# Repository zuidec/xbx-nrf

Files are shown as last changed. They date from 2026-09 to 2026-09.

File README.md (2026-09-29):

# xbx-nrf

A replacement bottom board for the **Xbox Series X|S controller (model 1914)**
built on a Nordic **nRF52840**, with a **2.4 GHz USB dongle** instead of Xbox
Wireless / Bluetooth: a low-latency proprietary link, like 8BitDo or Logitech
Lightspeed. The stock top board and shell stay.

> **Status:** early design and prototyping. Open tasks: [todo.md](todo.md).

## Architecture

```
┌─────────── Controller ───────────┐          ┌──── Dongle ────┐
│ Stock top board ─J3─ new board   │ 2.4 GHz  │ nRF52840 + USB │
│ buttons (PCAL6416)  nRF52840     │◀────────▶│ XInput / HID   │──▶ PC
│ power latch, boost  radio,       │ESB/Gazell│ gamepad        │
│ USB-C, 2×AA input   sticks,      │          │                │
│                     triggers,    │          │                │
│                     rumble       │          │                │
└──────────────────────────────────┘          └────────────────┘
```

## Design decisions (locked)

| Area | Decision |
|---|---|
| Target | Xbox Series X\|S (1914); Elite Series 2 (1797) maybe later |
| Scope | New **bottom board only**; stock top board, shell, triggers, motors reused |
| MCU | **nRF52840**: certified module (controller), Nordic PCA10059 (dongle) |
| Audio | **None in v1** |
| Wireless | **ESB/Gazell** 2.4 GHz; rumble/LED in ACK payloads |
| Multiplayer | One dongle: up to **7 paired**, **4 connected**; 1 kHz with 1–2, 500 Hz with 3–4 (time slots) |
| Dongle USB | **HID gamepad** (first) and **XInput** (`045E:028E`), switchable. No Xbox console support |
| Battery | **Rechargeable AAs only** (NiMH or regulated 1.5 V Li-ion AAs) |
| Power | Stock top board latch and boost converters, via J3 |
| Rumble | 2× **Allegro A3910**, stock wiring, 8 GPIOs |
| Buttons | Mostly via the top board's **PCAL6416** I2C expander |

> [!WARNING]
> **Never put a bare Li-ion cell on the AA contacts**: the stock boost
> converters pass it straight to the 3.3 V rail
> ([docs/hardware.md](docs/hardware.md)).

## Hardware

Our board plugs into the stock top board's 14-pin **J3**: power rails, USB, I2C
to the button expander, and Guide / Pair / power-hold signals.

| Doc | Covers |
|---|---|
| [docs/hardware.md](docs/hardware.md) | Top board power, J3 pinout, antennas |
| [docs/pcal6416.md](docs/pcal6416.md) | Button expander: button map, registers |
| [docs/a3910.md](docs/a3910.md) | Rumble drivers: wiring, logic table |

## Firmware

Two Zephyr apps, `firmware/xbx-nrf` (controller) and `firmware/dongle`, on the
**nRF Connect SDK v3.4.1** (pinned). Prototyped on Pro Micro nRF52840 boards;
the 1 kHz radio link works.

```sh
ncs-shell                                  # SDK toolchain environment
firmware/build-unsigned.sh xbx-nrf         # development build
firmware/build-signed.sh dongle <board>    # signed release build
```

| Doc | Covers |
|---|---|
| [docs/building.md](docs/building.md) | SDK setup, versions, build scripts |
| [docs/flashing.md](docs/flashing.md) | Flashing and debugging |
| [docs/protocol.md](docs/protocol.md) | Radio and USB HID protocols |
| [docs/gip.md](docs/gip.md) | Xbox GIP protocol notes (optional mode) |
| [docs/signing.md](docs/signing.md) | Firmware signing (MCUboot, keys) |

## Repository layout

```
docs/                project notes (Obsidian)
firmware/
  common/            shared code (include/protocol.h)
  xbx-nrf/           controller app
  dongle/            dongle app
  ncs-version        pinned SDK + toolchain
  check-sdk.sh       version check for the build scripts
  build-unsigned.sh  development build
  build-signed.sh    signed release build
pcb/xbx-nrf/         KiCad project (lib/: symbols, footprints, 3D)
references/          schematics, scans, datasheets, pinouts, CAD outline
todo.md              task list (Obsidian)
```

## References

- [Top board schematic](references/XB1%201914%20TOP%20BOARD.pdf)
- [Bottom board schematic](references/XB1_1914_BOTTOM_BOARD_SOME_VALUES.pdf)
- [SoC module schematic](references/XB1_1914_SOC_SOME_VALUES.pdf)
- [Connector pinouts and test points](references/controller-pinouts.txt)
- [SoC pinout](references/soc-pinout.txt)
- Datasheets: 
  [A1304](references/A1304-Datasheet.pdf),
  [A3910](references/A3910-datasheet.pdf),
  [PCAL6416A](references/PCAL6416A-datasheet.pdf)
- [AcidMods — XB1 controller PCB scans](https://acidmods.com/forum/index.php?topic=44547.120)
- [GP2040-CE](https://github.com/OpenStickCommunity/GP2040-CE)(XInput reference)

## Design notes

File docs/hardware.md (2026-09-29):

---
title: Hardware (stock top board & J3)
created: 2026-09-29
updated: 2026-09-29
tags:
  - xbx-nrf
  - reference
  - hardware
aliases:
  - hardware
  - J3
  - top board
---

# Hardware: stock top board & J3

The stock **top board** and the **J3** connector our bottom board plugs into.
Related: [[docs/pcal6416|PCAL6416 (buttons)]], [[docs/a3910|A3910 (rumble)]],
[[todo#1. Verify / reverse-engineer (stock hardware)]].

Sources: [[references/XB1 1914 TOP BOARD.pdf]],
[[references/controller-pinouts.txt]], [[references/soc-pinout.txt]].

> [!warning] No bare Li-ion cells
> U5/U6 are boost-only: a 4.2 V cell on the AA contacts passes through to the
> 3.3 V rail, above the nRF52840's 3.6 V max. Use rechargeable AAs (NiMH, or
> regulated 1.5 V Li-ion AAs).

## Top board power (stock, reused)

| Part | Function |
|---|---|
| Q6/Q7 | Battery → `3v/B+` switch; disconnects the AAs when USB is present |
| U5 TPS613221 | `3v/B+` → **3.3 V** (logic) |
| U6 TPS613226 | `3v/B+` → **3.6 V** (rumble) |
| U1 MP1476L | USB 5 V → `3v/B+`; powered on whenever USB is plugged in |
| SW13 + Q8 / SW2 + Q14 → Q9 | Guide or Pair powers on; J3 pin 9 holds it |

The latch is probably **not self-holding**: firmware must raise J3 pin 9 before
the button is released ([[todo#Power latch (top board)]]).

## J3: top ↔ bottom board connector

| Pin | Signal | Direction (bottom board) | Notes |
|---|---|---|---|
| 1 | 3.6 V | Power in | Rumble supply |
| 2 | GU (Guide) via D27 | Input | Active-low; pull-up on our board |
| 3 | 3v/B+ | Power in | Switched battery rail; battery sense |
| 4 | 3.3 V | Power in | nRF supply |
| 5 | SCL | Output | I2C to the PCAL6416 |
| 6 | LED control | Output | Guide LED (Q3) |
| 7 | SDA | Bidirectional | I2C to the PCAL6416 |
| 8 | USB D+ | Bidirectional | From the USB-C port |
| 9 | ~RESET / power hold | Output | High = power held + expander out of reset. *Verify* |
| 10 | USB D− | Bidirectional | |
| 11 | ? | — | Also J7 pin 1 (Play & Charge?). *Unknown* |
| 12 | VBUS | Input | USB detection |
| 13 | Pair sense via D30 | Input | Suspected; active-low. *Verify* |
| 14 | GND | — | |

*Verify* / *Unknown*: [[todo#J3/J5 connector (top ↔ bottom)]].

## Antennas (plan: reuse the stock ones)

Two feeds on the top board (`ANT` via J5/J6, `ANT1` via J8), each with a
matching network; the stock SoC board reaches them through coax connectors J1,
J2. We'll reuse the 2.4 GHz one, after verification (required before ordering
the PCB; [[todo#MCU / radio]]).

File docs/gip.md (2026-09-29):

---
title: GIP (Xbox One/Series USB protocol) notes
created: 2026-09-29
tags:
  - xbx-nrf
  - reference
  - usb
aliases:
  - GIP
  - MS-GIPUSB
---

# GIP: Gaming Input Protocol over USB

Microsoft's protocol for Xbox One/Series controllers. Only needed for an
optional future **GIP dongle mode** (impulse triggers on Windows; see
[[todo#Future / v2]]). Our own protocols: [[docs/protocol]].

Source: [[references/windows_protocols-ms-gipusb.pdf]] (MS-GIPUSB, 2024; §
numbers below). Reference implementation: GP2040-CE's Xbox One mode (MIT).

## Feasibility summary

- **Impulse triggers:** one simple message (`0x09`, below).
- **No authentication needed on PC:** list the opt-out interface GUID
  `7a34ce77-7de2-45c6-8ca4-0042c08bd94a` in the metadata; "the host succeeds
  the security exchange by default" (§5.1). Xbox consoles still require it.
- **Metadata** is the hard part: written as JSON, compiled to a binary blob with
  Microsoft's metadata compiler (in the "gipdocs" download, not in this spec).
  Windows requests it; Linux `xpad` doesn't.
- **Linux:** `xpad` supports GIP but sends trigger motor levels as 0, and Linux
  force feedback has only 2 rumble values. Trigger rumble would need SDL/Steam
  talking to the device directly. **Test with a genuine controller first**
  ([[todo#GIP dongle mode]]).
- **IDs:** the spec requires the maker's own VID; `xpad` only auto-binds known
  vendors (Microsoft's VID for a personal build, or bind manually).

## USB (§2.2.3–2.2.9)

| Item | Value |
|---|---|
| Device / interface class | `FF` / subclass `47` / protocol `D0` |
| Endpoints | Interface 0: 64-byte interrupt IN + OUT |
| Polling | "up to 4 ms / 250 Hz" (1 ms presumably allowed; verify) |
| Config attributes | `0xA0` (bus powered, remote wakeup) |
| Serial string | 32 hex digits = 64-bit Device ID |
| MS OS descriptor | String `MSFT100`, vendor code `0x90`; compatible ID `XGIP10` |

## Message header (§2.2.10)

| Byte | Field | Notes |
|---|---|---|
| 0 | Type | Bits 7:5 data class (000 command, 001 low latency, 011 audio), 4:0 message number |
| 1 | Flags | 7 fragment, 6 first fragment, 5 **system**, 4 **ACK requested**, 2:0 expansion index |
| 2 | Sequence | Wrapping, `0x00` reserved; global pool, except security / extended / audio / vendor messages (own pools) |
| 3 | Length | Payload bytes; bit 7 = length continues in the next byte |

MTU 64 bytes (commands, input). Larger messages (metadata) are fragmented with
ACKs (`0x01`) at least every 100 ms (§3.1.5.1–3.1.5.2).

## Startup (§1.3.1, §2.2.1–2.2.2)

1. Device sends **Hello** (`0x02`) every 500 ms until the host answers.
2. Host requests **metadata** (`0x04`, up to 4× at 500 ms; reply < 500 ms) or
   sends **Set Device State: Start** directly (metadata is cached by VID/PID
   + firmware major/minor).
3. **Start** → device sends **Status** (`0x03`) and a first **input report**
   reflecting the current state.
4. Host sends **Guide LED** (`0x0A`) and **motor** (`0x09`) commands.

## Messages we'd need

| Type | Dir | Message | Notes |
|---|---|---|---|
| `0x01` | ↕ | Protocol control (ACK) | Reliable / fragmented transfers |
| `0x02` | ↑ | Hello | 28 bytes: Device ID, VID, PID, FW major/minor/build/rev, HW version, RF/security/GIP versions (all `1.0`) |
| `0x03` | ↑ | Status | Extended format (4 bytes): on start, power off, charge/battery changes, every 1 s for 10 s then every 20 s |
| `0x04` | ↕ | Metadata request / response | Response fragmented, ends with Metadata Complete (flags `0xA0`) |
| `0x05` | ↓ | Set device state | `00` Start, `01` Stop, `04` Off, `05` Quiesce (clear motors), `07` Reset |
| `0x06` | ↕ | Security | Skipped via the opt-out GUID |
| `0x07` | ↑ | Guide button | 2-byte payload; after power-on, don't report the press until its first release |
| `0x09` | ↓ | **Direct motor** | Below |
| `0x0A` | ↓ | Guide LED | Pattern (`01` on, …) + intensity 0–47 % |
| `0x20` | ↑ | **Gamepad input** | Below; send only when something changed |

### Direct motor command (`0x09`, §3.1.5.6.1)

Header `09 00 <seq> 09`, then:

| Byte | Field | Notes |
|---|---|---|
| 4 | Command | `0x00` |
| 5 | Motor mask | bit 3 left impulse, 2 right impulse, 1 left grip, 0 right grip |
| 6 | Left impulse | 0–100 % |
| 7 | Right impulse | 0–100 % |
| 8 | Left grip (heavy) | 0–100 % |
| 9 | Right grip (light) | 0–100 % |
| 10 | Duration | ×10 ms; `0` = stop all |
| 11 | Delay | ×10 ms |
| 12 | Repeat | Count; `0` = play once |

Maps onto our `rumble[4]` (scale 0–100 → 0–255). Duration/delay/repeat could
be forwarded so the controller plays patterns itself.

### Gamepad input report (`0x20`, §3.1.5.6.1.1)

Header `20 00 <seq> 0E` (14-byte payload; `20` = 32 bytes with Share):

| Byte | Field |
|---|---|
| 4 | `0x04` Menu, `0x08` View, `0x10` A, `0x20` B, `0x40` X, `0x80` Y |
| 5 | `0x01` Up, `0x02` Down, `0x04` Left, `0x08` Right, `0x10` LB, `0x20` RB, `0x40` LS, `0x80` RS |
| 6–7 | Left trigger 0–1023 |
| 8–9 | Right trigger 0–1023 |
| 10–17 | LX, LY, RX, RY: −32768…32767 |
| 18 | *(Share variant)* Console Function Map: `0x01` while Share is held, else `0x00`; rest zero |

Guide isn't in this report (it's `0x07`). Bit order differs from our radio
`buttons` (XInput layout), so the dongle remaps.

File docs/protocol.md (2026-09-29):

---
title: xbx-nrf protocols (radio + USB HID)
created: 2026-09-29
tags:
  - xbx-nrf
  - firmware
  - reference
aliases:
  - protocol
  - radio protocol
  - HID report
---

# xbx-nrf protocols

Two links: **radio** (controller ↔ dongle, implemented) and **USB HID** (dongle
↔ PC, planned). XInput and GIP modes reuse the radio data; see [[docs/gip]] for
GIP. Tasks: [[todo#Link]], [[todo#Dongle]].

## Radio (controller ↔ dongle)

Source of truth: `firmware/common/include/protocol.h`. **Version 1**
(`XBX_PROTOCOL_VERSION`); both boards must run the same version.

### Link

| Setting | Value |
|---|---|
| Protocol | Nordic ESB, dynamic payload length, selective auto-ACK |
| Bit rate | 2 Mbps, fast ramp-up |
| Channel | 76 (2476 MHz), fixed for now (`XBX_RF_CHANNEL`) |
| Address | base 0 `58 42 58 31` ("XBX1"), prefix `E7`, pipe 0 (fixed until pairing) |
| TX power | +8 dBm, both ends (`XBX_TX_POWER_DBM`) |
| Roles | Controller = PTX, dongle = PRX |
| Report rate | 1000 Hz from hardware TIMER3 (`XBX_REPORT_PERIOD_US`) |
| Retries | 1, 450 µs apart (ESB minimum 435 µs); stale reports are flushed, never resent late |
| Max payload | 32 bytes (`CONFIG_ESB_MAX_PAYLOAD_LENGTH`) |

Every 1 ms the controller sends an **input report**. The dongle's ESB ACK
carries the **output report** queued for it (one is always kept queued), so
rumble/LED data costs no extra transmissions. All fields are little-endian.

### Input report (controller → dongle), 23 bytes

| Offset | Size | Field | Notes |
|---|---|---|---|
| 0 | 1 | `type` | `0x01` (`XBX_MSG_INPUT`) |
| 1 | 2 | `seq` | +1 per report actually sent; gaps = lost over the air. Gap ≥ 0x8000 = controller restart |
| 3 | 2 | `buttons` | Bitmap below, 1 = pressed |
| 5 | 2 | `lx` | Left stick X, −32768…32767 |
| 7 | 2 | `ly` | Left stick Y |
| 9 | 2 | `rx` | Right stick X |
| 11 | 2 | `ry` | Right stick Y |
| 13 | 2 | `lt` | Left trigger, 0…1023 |
| 15 | 2 | `rt` | Right trigger, 0…1023 |
| 17 | 1 | `buttons_ext` | bit 0 Share, bit 1 Pair |
| 18 | 1 | `battery` | 0…100 %, `0xFF` = unknown |
| 19 | 4 | `timestamp_us` | Controller uptime at send (latency tests) |

`buttons` uses the **XInput `wButtons` layout**, so XInput mode passes it
through:

| Bit | Button | Bit | Button |
|---|---|---|---|
| 0 | D-pad up | 8 | LB |
| 1 | D-pad down | 9 | RB |
| 2 | D-pad left | 10 | Guide |
| 3 | D-pad right | 11 | *(unused)* |
| 4 | Menu (XInput START) | 12 | A |
| 5 | View (XInput BACK) | 13 | B |
| 6 | LS (stick click) | 14 | X |
| 7 | RS | 15 | Y |

### Output report (dongle → controller, ACK payload), 8 bytes

| Offset | Size | Field | Notes |
|---|---|---|---|
| 0 | 1 | `type` | `0x02` (`XBX_MSG_OUTPUT`) |
| 1 | 1 | `seq` | +1 per report queued |
| 2 | 4 | `rumble[4]` | Heavy, light, LT, RT; 0…255 |
| 6 | 1 | `led` | Guide LED brightness, 0…255 |
| 7 | 1 | `flags` | Reserved, 0 |

### Changing the protocol
- Bump `XBX_PROTOCOL_VERSION` and the `_Static_assert` sizes; update this page.
- Mismatched versions show up as `bad` packets on the dongle (length/type
  check).
- Planned for v2: pairing, multiple controllers, time slots
  ([[#Pairing & multiple controllers (planned, protocol v2)]]).

| Version | Change |
|---|---|
| 0 | Initial: 22-byte input report, 8-bit `seq` |
| 1 | 16-bit `seq` (23-byte input report) |

## Pairing & multiple controllers (planned, protocol v2)

> [!warning] Draft
> Design agreed 2026-09-29, not implemented. Numbers marked *(tune)* are
> starting values to adjust on hardware.

### Requirements
- A controller only ever talks to the dongle it's paired with.
- Several dongle/controller sets work side by side.
- One dongle: **up to 7 paired** controllers, **up to 4 connected**.
- Report rate: **1 kHz** with 1–2 connected, **500 Hz** with 3–4.
- Pairing needs a deliberate action on **both** sides, and doesn't interrupt
  controllers already playing on that dongle.

### Addresses and channels
- ESB gives a receiver 8 **pipes**: pipe 0 on base address 0, pipes 1–7 on base
  address 1, each pipe with its own 1-byte prefix.

| Pipe | Address | Use |
|---|---|---|
| 0 | Fixed **pairing address** `"XBXP"` + prefix `E7`, same on every dongle | Pairing only; enabled only while the dongle is in pairing mode |
| 1–7 | Dongle's **random base address 1** + 7 distinct random prefixes | One per paired controller |

- The radio drops packets for addresses it isn't listening on (plus CRC), so a
  controller can't reach another dongle, and nobody reaches the pairing pipe
  unless that dongle is in pairing mode.
- Random addresses are chosen once, at first use; patterns resembling the
  preamble (mostly `0x55`/`0xAA`) are rejected.
- **Channel:** each dongle picks the quietest channel (RSSI sampling) from a
  fixed **candidate list**, at first use: **24, 49, 74, 76, 78** *(tune)*,
  i.e. 2424–2478 MHz in the gaps between Wi-Fi channels 1/6/11, clear of BLE
  advertising. Channel hopping later follows a per-dongle sequence.
- **IDs:** each nRF52840's factory-unique 64-bit `DEVICEID` (FICR).

### ESB constraint: answers take two transmissions
The receiver ACKs ~150 µs after a packet arrives, before firmware has read it,
so an ACK can only carry what was queued **before** the packet came in. Every
request is therefore repeated: the first copy gets a plain ACK ("heard you"),
the dongle then queues its answer, and a later copy gets the answer in its ACK.
The controller simply repeats each message every ~2 ms until the answer
arrives.

### Pairing mode
| Side | Enter | While active | Timeout |
|---|---|---|---|
| Dongle | Press its button; automatic at plug-in if never paired | Enables pipe 0 on its own channel; time slots keep running; LED fast blink | 30 s *(tune)* |
| Controller | Hold **Pair** ~3 s, or power on with Pair held | Drops its current link, scans; Guide LED fast blink | 30 s *(tune)* |

Both windows just need to overlap; press order doesn't matter.

### Exchange

```
controller                                   dongle (own channel)
  scan candidate channels:
  PAIR_REQ on pipe 0 (pairing address)  ─▶   (pipe 0 open only in pairing mode)
      no ACK → next channel (~0.6 ms each)
      ACK    → stay, repeat every ~2 ms
                                              check RSSI, version, ambiguity;
                                              pick pipe; queue PAIR_OFFER
  PAIR_REQ (repeat)                     ─▶
                                        ◀─   ACK: PAIR_OFFER
  check nonce; switch to assigned pipe
  PAIR_CONFIRM on its pipe (repeat)     ─▶
                                              save entry to flash;
                                              queue PAIR_DONE on that pipe
  PAIR_CONFIRM (repeat)                 ─▶
                                        ◀─   ACK: PAIR_DONE
  save to flash; both leave pairing mode (LEDs solid), dongle closes pipe 0
  controller joins normally (below)
```

Once both sides are in pairing mode, this takes well under a second.

**Dongle checks on `PAIR_REQ`** (step "check" above):
- **Proximity:** RSSI ≥ **−50 dBm** *(tune)*, i.e. held close; otherwise
  ignored.
- **Version:** `proto_ver` must match; otherwise `PAIR_OFFER` with status
  "version mismatch" and both show the error blink.
- **Ambiguity:** a second, different `ctrl_id` in the same window → abort, error
  blink.
- **Pipe:** known `ctrl_id` → same pipe; else a free pipe; else the **least
  recently connected** entry's pipe.

**Controller checks on `PAIR_OFFER`:**
- `nonce` must echo its own (not someone else's offer).
- Offers from two different `dongle_id`s in one window (two dongles pairing
  nearby) → abort, error blink.

**Commit order:** the dongle saves when it receives `PAIR_CONFIRM` on the new
pipe (proof the controller has the offer and switched); the controller saves
when it receives `PAIR_DONE`. Flash writes run from a work queue, never in the
radio interrupt.

### Pairing messages
Payloads (little-endian, sizes to finalize):

| Type | Message | Pipe | Fields | Size |
|---|---|---|---|---|
| `0x10` | PAIR_REQ | 0 | `ctrl_id`[8], `proto_ver`, `nonce`[4] | 14 |
| `0x11` | PAIR_OFFER | 0 (ACK) | `status`, `dongle_id`[8], `nonce`[4], `base_addr1`[4], `prefix`, `pipe` (1–7), `channel` | 21 |
| `0x12` | PAIR_CONFIRM | assigned | `ctrl_id`[8], `dongle_id`[8] | 17 |
| `0x13` | PAIR_DONE | assigned (ACK) | `status` | 2 |

Byte 0 of each payload is the type. `status`: `0` ok, `1` version mismatch, `2`
aborted (ambiguity).

### Failure handling
| Situation | Result |
|---|---|
| Only one side in pairing mode | Controller keeps scanning; both time out; nothing changes |
| Controller too far away | Ignored; timeout |
| Two controllers at one dongle | Dongle aborts, error blink |
| Two dongles pairing nearby | Controller aborts, error blink |
| Version mismatch | Error blink on both |
| `PAIR_DONE` lost | Controller repeats `PAIR_CONFIRM`; dongle re-sends `PAIR_DONE` |
| Controller never gets `PAIR_DONE` | Controller saves nothing; the dongle's entry is reused on re-pair or replaced later |
| Re-pairing a known controller | Same pipe, entry updated |

### Stored data (Zephyr settings, flash)
- **Dongle:** `base_addr1`, 7 prefixes, channel; 7 entries of `ctrl_id`, pipe,
  last-connected counter.
- **Controller:** `dongle_id`, `base_addr1`, prefix, pipe, channel.
- Factory reset: e.g. Pair + View held at power-on *(tune)*; the dongle's
  button held ~10 s *(tune)*.

### Time slots (TDMA)
One radio can't receive two controllers at once, so the dongle runs a
repeating **frame** and gives each connected controller its own **slot**:

| Connected | Frame | Slots | Rate per controller |
|---|---|---|---|
| 1–2 | 1 ms | 2 × 500 µs | 1000 Hz |
| 3–4 | 2 ms | 4 × 500 µs | 500 Hz |

- A transaction (report + ACK) takes ~200–300 µs, so 500 µs slots leave margin.
- **Sync:** each ACK carries a timing correction (report arrival vs. slot
  start, measured by the dongle). The controller trims its TIMER3 period.
  Crystal drift is ~20 ns/ms, so per-frame correction is plenty.
- **No retries** within a frame: a lost report is replaced by the next one.
- **Frame changes** (2nd → 3rd controller and back): the dongle announces the
  new frame length and each slot in ACK payloads, effective from a given frame
  number, so all controllers switch together.
- Pairing traffic on pipe 0 is rare and short; it may cost an occasional report
  in an active slot.

### Connecting and disconnecting
- **Join:** a paired, unsynced controller sends reports on its pipe every
  ~10 ms with random jitter until an ACK assigns it a slot. Rare collisions with
  active slots cost at most one report.
- **Full (4 connected):** the dongle answers with a "full" status; the
  controller shows it and retries slowly, then powers off after a timeout.
- **Drop:** no report from a slot for ~100 ms *(tune)* → slot freed, USB reports
  a disconnect.
- **Player number** = slot (USB interface order; optionally shown on the Guide
  LED).

### Message changes (v2)
| Type | Message | Direction |
|---|---|---|
| `0x01` | Input report (unchanged) | controller → dongle |
| `0x02` | Output report + sync fields (below) | dongle → controller |
| `0x10`–`0x13` | Pairing ([[#Pairing messages]]) | both |

Output report additions (sizes to finalize): slot index, frame length, timing
correction (signed µs), status (`ok` / `full` / `frame change at N`), and link
quality (RSSI, for [[todo#Dynamic TX power]]).

### Later
- **Encryption / authentication:** ESB has none; a key from pairing (ECDH) +
  AES-CCM per packet would stop spoofed input. The nRF52840 has hardware for
  both. Not planned for v1.

## USB HID mode (dongle ↔ PC), planned

> [!warning] Draft
> Not implemented yet (M2). The layout below is the starting proposal; finalize
> it with the report descriptor and update this page.

- Standard HID gamepad (Generic Desktop / Game Pad), Zephyr USB HID class.
- Our own VID/PID (not Microsoft's); 1 ms interrupt IN endpoint.
- **One HID interface per player slot (4)**, so the OS sees 4 gamepads. XInput
  mode likewise emulates the **Xbox 360 Wireless Receiver** (4 interfaces with
  connect/disconnect; supported by `xpad`, Steam, Windows).
- Carries the full radio data: 16-bit sticks, 10-bit triggers, every button
  including Share.

### Input report (dongle → PC), proposal

| Offset | Size | Field | HID usage |
|---|---|---|---|
| 0 | 1 | Report ID `0x01` | |
| 1 | 2 | Buttons 1–16 | Button page, same bit order as radio `buttons` |
| 3 | 1 | Buttons 17–18 (Share, Pair) + 6 bits padding | Button page |
| 4 | 2 | Left stick X | Generic Desktop X, −32768…32767 |
| 6 | 2 | Left stick Y | Y |
| 8 | 2 | Right stick X | Rx |
| 10 | 2 | Right stick Y | Ry |
| 12 | 2 | Left trigger | Z, 0…1023 |
| 14 | 2 | Right trigger | Rz, 0…1023 |

### Output report (PC → dongle), proposal

| Offset | Size | Field | HID usage |
|---|---|---|---|
| 0 | 1 | Report ID `0x02` | |
| 1 | 4 | Rumble heavy, light, LT, RT (0…255) | Vendor page `0xFF00` |
| 5 | 1 | Guide LED (0…255) | Vendor page `0xFF00` |

Maps 1:1 onto the radio output report. Games won't use it (no standard HID
rumble); it's for our own tools and possibly Steam later.

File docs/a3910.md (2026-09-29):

---
title: A3910 rumble motor driver (U4/U5, bottom board)
created: 2026-09-28
updated: 2026-09-29
tags:
  - xbx-nrf
  - reference
  - ic
aliases:
  - A3910
  - rumble driver
---

# A3910 — rumble motor drivers (U4, U5 on the bottom board)

Allegro dual half-bridge driver. The stock bottom board uses two, one
half-bridge per rumble motor. **Our board copies this: 2× A3910, 8 GPIOs.**
Tasks: [[todo#Rumble]].

> [!note] Designator clash
> Bottom board **U4/U5 = A3910**; top board **U4 =
> [[docs/pcal6416|PCAL6416]]**.

Sources: [[references/XB1_1914_BOTTOM_BOARD_SOME_VALUES.pdf]],
[[references/A3910-datasheet.pdf]] (Rev. 3), [[references/soc-pinout.txt]].

## Key specs

| Parameter | Value |
|---|---|
| Supply (VBB) | 2.5–5.5 V; **3.6 V** here (J3 pin 1) |
| Output current | 500 mA max per output |
| R<sub>DS(on)</sub> at 3 V, 400 mA | high side 1.1 Ω typ / 1.4 max, low side 0.5 / 0.65 Ω |
| Supply current | 0.3 mA typ (50 kHz PWM); **< 1 µA sleep** |
| Logic thresholds | V<sub>IL</sub> ≤ 0.5 V, **V<sub>IH</sub> ≥ VBB/2 = 1.8 V**: 3.3 V GPIOs are fine |
| Input pull-downs | 100 kΩ; 33 µA per input held high |
| Logic input abs. max | −0.3 to 6 V |
| Protection | Crossover protection; thermal shutdown 165 °C |
| Thermal resistance | 49 °C/W (4-layer), 92 °C/W (2-layer) |
| Package | 2 × 2 mm DFN-8 + exposed pad, 0.5 mm pitch |
| Part | **A3910EEETR-T** (LCSC C150818) |

## Pinout

| Pin | Name | Function |
|---|---|---|
| 1 | HIN1 | High-side input, bridge 1 |
| 2 | LIN1 | Low-side input, bridge 1 |
| 3 | LIN2 | Low-side input, bridge 2 |
| 4 | HIN2 | High-side input, bridge 2 |
| 5 | OUT2 | Output 2 |
| 6 | GND | Ground |
| 7 | VBB | Supply |
| 8 | OUT1 | Output 1 |
| 9 (EP) | PAD | → GND (thermal) |

## Logic table

Motors connect **between OUTx and GND**.

| HINx | LINx | OUTx | Motor |
|---|---|---|---|
| 0 | 0 | Hi-Z | **Coast**; sleep if all four inputs < 100 mV |
| 1 | 0 | High | **Drive** |
| 0 | 1 | Low | **Brake** |
| 1 | 1 | Hi-Z | Coast (crossover protection) |

## Stock wiring (bottom board)

| Driver | Output | Motor | Output TP | Input TPs | Clamp diode |
|---|---|---|---|---|---|
| U4 | OUT1 (8) | **LT** impulse trigger | TP27 | TP104–TP107 | CR3 |
| U4 | OUT2 (5) | **Heavy** (left grip) | TP28 | ↑ | CR1 |
| U5 | OUT1 (8) | **RT** impulse trigger | TP29 | TP108–TP111 | CR4 |
| U5 | OUT2 (5) | **Light** (right grip) | TP30 | ↑ | CR2 |

- Motor pads: SQ1/2 (LT), SQ3/4 (Heavy), SQ5/6 (RT), SQ7/8 (Light); second
  terminal to GND.
- CR1–CR4: clamp diodes output → GND. C5/C6/C15/C16 across the motors: not
  fitted. VBB decoupling values: not recorded.
- SoC pins (from `soc-pinout.txt`): U4 pins 1–4 → 49, 50, 48, 47; U5 pins 1–4 →
  59, 61, 18, 62. TP → pin mapping unconfirmed.

## Our design

8 GPIOs (HIN + LIN per motor): every motor can drive, brake and coast.

> [!tip] Freeing pins later
> Tie **LIN to GND on Heavy and Light** (−2 GPIOs). They then only drive and
> coast, which is fine for grip motors; LT/RT keep fast braking.

### Schematic checklist
- [ ] 2× A3910EEETR-T, VBB from J3 pin 1, exposed pad to GND.
- [ ] VBB decoupling per driver, ≥ 1 µF + 100 nF (check against the stock
      board).
- [ ] Clamp diodes OUTx → GND (small Schottky, like CR1–CR4).
- [ ] Optional footprints for capacitors across the motors (EMI).
- [ ] Motor pads at the stock SQ1–SQ8 positions.
- [ ] 8 GPIOs (any nRF52840 pin can do PWM).

### KiCad
- Footprint: `Package_DFN_QFN:DFN-8-1EP_2x2mm_P0.5mm_EP0.9x1.6mm`; check the
  pads against datasheet p. 6. 2–4 thermal vias in the pad.
- Symbol: not in KiCad; draw one or import LCSC C150818 with `easyeda2kicad`.

## Firmware notes

- **Strength:** PWM on HINx, LINx = 0. All 8 inputs fit on 2 of the 4 PWM
  peripherals.
- **Stop:** HINx = 0, LINx = 1 briefly, then 0/0.
- No dead time needed between HIN and LIN (crossover protection).
- **Idle:** all inputs low → both chips sleep.
- **Power off:** set the inputs low before releasing the hold, so the chips
  aren't back-powered through them.
- PWM ≥ 20 kHz, so the motors don't whine.

## To verify
- [ ] TP104–TP111 → input pin mapping.
- [ ] Stock VBB decoupling and CR1–CR4 part values.
- [ ] Motor current at full drive (vs. 500 mA and the 3.6 V boost converter).

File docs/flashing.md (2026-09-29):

---
title: Flashing & debugging the nRF52840 boards
created: 2026-09-28
updated: 2026-09-29
tags:
  - xbx-nrf
  - firmware
  - howto
aliases:
  - flashing
  - programming
  - SWD
---

# Flashing & debugging the nRF52840 boards

Related: [[docs/building]], [[docs/signing]], [[todo#5. Firmware]].

> [!warning] Mostly untested
> ✅ = verified on hardware. Everything else is from docs and may depend on tool
> versions; mark it once it works.

## Hardware

| Board | Role | Built-in programming | Board target |
|---|---|---|---|
| Pro Micro nRF52840 (nice!nano clone) | Controller prototype, dongle stand-in | nice!nano UF2 bootloader ✅ | `promicro_nrf52840/nrf52840/uf2` |
| Nordic nRF52840 Dongle (PCA10059) | Dongle | Nordic USB DFU bootloader | `nrf52840dongle/nrf52840` |
| Custom bottom board | Controller | None; SWD only | TBD |

| Debug probe | Notes |
|---|---|
| **ST-Link** (on hand) | OpenOCD / pyOCD / probe-rs. May not unlock a locked chip ([[#Locked chip (APPROTECT)]]) |
| Raspberry Pi Debug Probe | ~$12 CMSIS-DAP fallback that can ([[#Raspberry Pi Debug Probe (CMSIS-DAP)]]) |

Neither works with Nordic's J-Link-only tools (`nrfutil device`, nRF Connect
Programmer over SWD, the nRF Connect VS Code debugger).

Board overlay naming: see [[docs/building#Board overlays]].

## SWD wiring

| Probe | Target |
|---|---|
| SWDIO | SWDIO |
| SWCLK | SWCLK |
| GND | GND |
| 3.3 V / VAPP / TVCC | Target 3.3 V (**sense only**; power the target from USB) |
| NRST (optional) | RESET |

An official ST-Link won't connect without the target 3.3 V on its sense pin.

- **Pro Micro:** SWDIO/SWCLK pads on the underside (check the clone's
  silkscreen).
- **PCA10059:** pads on the underside (*nRF52840 Dongle User Guide*).
- **Custom board:** SWD connector or Tag-Connect footprint
  ([[todo#MCU / radio]]).

> [!warning] SWD flashing erases the bootloader
> A full erase or recover wipes the UF2 / Nordic USB bootloader; restore it with
> [[#Restoring bootloaders]].

Paths below use `$HEX` / `$ELF` for `<app>/build/<app>/zephyr/zephyr.hex` /
`.elf`.

## ST-Link + OpenOCD

### Flash
```sh
openocd -f interface/stlink.cfg -f target/nrf52.cfg \
        -c "program $HEX verify reset exit"
```

### Debug
```sh
openocd -f interface/stlink.cfg -f target/nrf52.cfg   # GDB server on :3333
arm-none-eabi-gdb $ELF -ex "target extended-remote :3333"
```
VS Code: **Cortex-Debug** (`"servertype": "openocd"`, configFiles
`interface/stlink.cfg`, `target/nrf52.cfg`).

### RTT logging (optional)
With OpenOCD running, in `telnet localhost 4444`:
```
rtt setup 0x20000000 0x40000 "SEGGER RTT"
rtt start
rtt server start 9090 0
```
Then `nc localhost 9090`. Zephyr: `CONFIG_USE_SEGGER_RTT=y`,
`CONFIG_LOG_BACKEND_RTT=y`.

### pyOCD alternative
```sh
pyocd pack install nrf52840      # once
pyocd flash -t nrf52840 $HEX
pyocd gdbserver -t nrf52840
```

## Raspberry Pi Debug Probe (CMSIS-DAP)

Same as the ST-Link with `interface/cmsis-dap.cfg`, plus reliable chip unlock
and a built-in USB-UART for logs.

### Wiring

| Probe port | Pins | Connect to |
|---|---|---|
| **D** (debug) | SC (SWCLK), GND, SD (SWDIO) | Target SWD pads |
| **U** (UART) | TX, GND, RX | Target UART (TX ↔ RX crossed) |

3.3 V I/O, no sense pin, no reset wire (reset over SWD works).

### OpenOCD
```sh
openocd -f interface/cmsis-dap.cfg -f target/nrf52.cfg \
        -c "program $HEX verify reset exit"                  # flash
openocd -f interface/cmsis-dap.cfg -f target/nrf52.cfg       # GDB server
openocd -f interface/cmsis-dap.cfg -f target/nrf52.cfg \
        -c "init; nrf52_recover; exit"                       # unlock
```

### probe-rs (alternative)
Single binary with flashing, RTT and unlock; also supports the ST-Link.
```sh
probe-rs download --chip nRF52840_xxAA $HEX
probe-rs erase --chip nRF52840_xxAA --allow-erase-all   # unlock
probe-rs attach --chip nRF52840_xxAA $ELF               # RTT viewer
probe-rs gdb --chip nRF52840_xxAA                       # GDB server
```
Install: installer from probe-rs.rs (not packaged for Tumbleweed), plus its
udev rules.

### UART logs
```sh
picocom -b 115200 /dev/ttyACM1   # the probe's UART; see `ls /dev/ttyACM*`
```
Needs the Zephyr console on the UART pins wired to the probe.

## Locked chip (APPROTECT)

Newer nRF52840s lock debug access unless the firmware unlocks it: the probe
connects but can't halt or read memory. **Recovering** = full erase via
Nordic's CTRL-AP (bootloader and UICR included).

1. OpenOCD 0.12+ with the **DAP-mode** ST-Link interface:
   ```sh
   openocd -f interface/stlink-dap.cfg -f target/nrf52.cfg \
           -c "init; nrf52_recover; exit"
   ```
2. Without `nrf52_recover`, write CTRL-AP (AP 1) directly:
   ```
   nrf52.dap apreg 1 0x04 0x01   ; ERASEALL
   sleep 500                      ; (poll 0x08 until 0)
   nrf52.dap apreg 1 0x04 0x00
   nrf52.dap apreg 1 0x00 0x01   ; reset
   nrf52.dap apreg 1 0x00 0x00
   ```
3. If the ST-Link can't (old/clone firmware without DAP mode), recover with a
   CMSIS-DAP probe.

Keep debug unlocked during development: Zephyr's APPROTECT Kconfig choice
(`CONFIG_NRF_APPROTECT_USE_UICR` default, `_LOCK`, `_USER_HANDLING`); check
the options in your SDK.

## Pro Micro nRF52840 — UF2 bootloader (no probe) ✅

nice!nano UF2 bootloader (Adafruit nRF52). The `uf2` board variant links the
app after the SoftDevice area it expects.

1. Short **RST to GND twice** quickly: the LED fades and a `NICENANO` drive
   appears.
2. Build, then flash:
   ```sh
   firmware/build-unsigned.sh xbx-nrf
   cd firmware/xbx-nrf && west flash    # copies zephyr.uf2 to the drive
   ```
   `west flash` needs the drive mounted (`udisksctl mount -b /dev/sdX`), or copy
   `build/<app>/zephyr/zephyr.uf2` onto it by hand.
3. The app reboots; logs appear on `/dev/ttyACM*` (USB CDC console).

> [!note] P0.13 = external VCC switch
> On nice!nano-style boards P0.13 switches the `VCC` pin (low = on). Drive it
> low when powering sticks or sensors from `VCC`, or use `3.3V` instead.

## nRF52840 Dongle (PCA10059) — USB DFU (no probe)

1. Press the sideways **RESET** button (red LED pulses).
2. Package and flash:
   ```sh
   nrfutil install nrf5sdk-tools
   nrfutil nrf5sdk-tools pkg generate --hw-version 52 --sd-req=0x00 \
       --application $HEX --application-version 1 dongle.zip
   nrfutil nrf5sdk-tools dfu usb-serial -pkg dongle.zip -p /dev/ttyACM0
   ```
   GUI alternative: nRF Connect for Desktop → Programmer.

The default board target leaves room for the Nordic bootloader. If SWD erased
it, build for `nrf52840dongle/nrf52840/bare` instead.

## Restoring bootloaders

- **Pro Micro:** nice!nano bootloader hex (nice!nano / Adafruit nRF52
  bootloader releases), over SWD:
  ```sh
  BL=nice_nano_bootloader-0.9.2_s140_6.1.1.hex
  openocd -f interface/stlink.cfg -f target/nrf52.cfg \
          -c "init; reset halt; nrf5 mass_erase" \
          -c "program $BL verify reset exit"
  ```
- **PCA10059:** nRF5 SDK `examples/dfu/open_bootloader/pca10059_usb_debug`,
  over SWD.

## Troubleshooting

| Symptom | Likely cause |
|---|---|
| ST-Link won't connect ("target voltage 0 V") | Target 3.3 V not on the sense pin |
| Connects, can't halt or read memory | Chip locked → [[#Locked chip (APPROTECT)]] |
| Dongle app doesn't run after SWD flashing | Bootloader gone → build for the `bare` variant |
| No UF2 drive | Double tap too slow; charge-only USB cable |
| `west flash`: no matching UF2 partition | Drive not mounted |
| No `/dev/ttyACM*` after flashing | App crashed early; user not in `dialout` |
| Board overlay has no effect | Wrong filename ([[docs/building#Board overlays]]) |

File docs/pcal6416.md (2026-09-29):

---
title: PCAL6416 (U4, top board)
created: 2026-09-28
updated: 2026-09-29
tags:
  - xbx-nrf
  - reference
  - ic
aliases:
  - U4
  - PCAL6416
  - PCAL6416A
---

# PCAL6416A — U4 on the top board

16-bit I2C GPIO expander (NXP, 24-pin HWQFN) on the stock **top board**. Reads
most buttons; our board talks to it over I2C through J3. Tasks:
[[todo#PCAL6416 expander (top board)]].

Sources: [[references/XB1 1914 TOP BOARD.pdf]],
[[references/PCAL6416A-datasheet.pdf]] (Rev. 7.1; § numbers below).

## Key specs

| Parameter | Value | Datasheet |
|---|---|---|
| Supply (VDD(I2C-bus), VDD(P)) | 1.65–5.5 V; both **3.3 V** here | §1 |
| I2C speed | **400 kHz max** | §2 |
| Address | `0b010000A`, ADDR high → **`0x21`** | §7.1, Table 5 |
| Standby current | 1 µA typ / 3.2 µA max | Table 34 |
| Active current (400 kHz reads) | 40 µA typ / 75 µA max | Table 34 |
| Internal pull-up/down | 100 kΩ typ (50–150 kΩ) | §7.4.8, Table 34 |
| Port inputs | 5 V tolerant, 0.7×/0.3× VDD(P) | §2, Table 32 |
| Reset | tw(rst) ≥ 30 ns, trec(rst) ≥ 200 ns | Table 36 |
| Power-up state | All inputs, **pulls disabled**, interrupts masked | §7.4, Table 6 |

## Connections

| U4 pin | Name | Connected to | Notes |
|---|---|---|---|
| 23 | VDD(I2C-bus) | 3.3 V | I2C logic level |
| 21 | VDD(P) | 3.3 V | Core + port supply |
| 18 | ADDR | 3.3 V | → **0x21** |
| 20 | SDA | R41 → TP30 → **J3 pin 7** | C36 51 pF to GND |
| 19 | SCL | TP31 → **J3 pin 5** | C46 100 pF to GND |
| 22 | ~INT | **Not connected** | Poll the inputs |
| 24 | ~RESET | R4 (0 Ω) → **J3 pin 9** | EG2 + C37 to GND; same net as the power hold |
| 9, 25 | VSS, EPAD | GND | |

> [!important] Reset = power hold line
> J3 pin 9 also holds the power latch on (R7 → D26 → Q9). The expander is in
> reset whenever the hold is released, and loses its configuration at every
> power-up. Configure it after asserting the hold.

> [!question] I2C pull-ups
> None on the top board near U4; probably on the stock bottom board. **Put
> pull-ups on our board** (e.g. 4.7 kΩ to 3.3 V) and confirm the top board has
> none.

## Port → button map

Buttons switch to GND with no external pull-ups: enable the internal pull-ups;
inputs are **active-low**.

| Port | Pin | Bit | Button | Switch | Test point | Notes |
|---|---|---|---|---|---|---|
| P00 | 1 | 0 | **Share** | SW14-SH | TP39 | |
| P01 | 2 | 1 | **X** | SW7-X | TP22 | |
| P02 | 3 | 2 | *(unused)* | — | TP27 | USB-C CC sense option; R55/R56 not fitted |
| P03 | 4 | 3 | **Y** | SW8-Y | TP23 | |
| P04 | 5 | 4 | **RB** | SW3-RB | TP20 | |
| P05 | 6 | 5 | **LB** | SW1-LB | TP19 | |
| P06 | 7 | 6 | *(unused)* | — | FT4 | Factory test pad |
| P07 | 8 | 7 | **Menu** | SW5-MN | TP24 | |
| P10 | 10 | 8 | **Pair (Sync)** | SW2-SY | TP18 | Also powers on via R46 → Q14 |
| P11 | 11 | 9 | **D-pad Up** | SW6-DU | TP16 | Series resistor R3? |
| P12 | 12 | 10 | **D-pad Right** | SW10-DR | TP14 | R4? |
| P13 | 13 | 11 | **D-pad Left** | SW9-DL | TP15 | R5? |
| P14 | 14 | 12 | **D-pad Down** | SW12-DD | TP44 | R6? |
| P15 | 15 | 13 | **View** | SW4-VW | TP25 | |
| P16 | 16 | 14 | *(unused)* | — | TP26 | |
| P17 | 17 | 15 | **A** | SW11-A | TP21 | |

`?` designators are as in the source schematic. Each switch has an unfitted
diode footprint (likely ESD).

### Buttons **not** on the expander

| Button | Where | Path |
|---|---|---|
| Guide | Top board SW13 | J3 pin 2 via D27; active-low, pull-up on our board. Also powers on via Q8 |
| Pair (sense) | Top board SW2 | J3 pin 13 via D30 (suspected; [[todo#Power latch (top board)]]) |
| B | **Bottom board** | TP41 via R29 (100 Ω); recreate on our board |
| LSC / RSC | **Bottom board** | Via R16 / R21 (33 Ω); recreate on our board |

## Register map

Checked against the datasheet (§7.3, Table 6).

| Cmd | Register | Access | Power-up | Our setting |
|---|---|---|---|---|
| `0x00` / `0x01` | Input port 0 / 1 | R | pin state | **Read every cycle** |
| `0x02` / `0x03` | Output port 0 / 1 | R/W | `0xFF` | Unused |
| `0x04` / `0x05` | Polarity inversion 0 / 1 | R/W | `0x00` | Optional `0xFF` (pressed = 1) |
| `0x06` / `0x07` | Configuration 0 / 1 (1 = input) | R/W | `0xFF` | Leave |
| `0x40`–`0x43` | Output drive strength | R/W | `0xFF` | Unused |
| `0x44` / `0x45` | Input latch 0 / 1 | R/W | `0x00` | Leave off |
| `0x46` / `0x47` | Pull-up/down **enable** 0 / 1 | R/W | **`0x00`** | **`0xFF`**, must be written |
| `0x48` / `0x49` | Pull-up/down **select** 0 / 1 (1 = up) | R/W | `0xFF` | Leave |
| `0x4A` / `0x4B` | Interrupt mask 0 / 1 | R/W | `0xFF` | Leave |
| `0x4C` / `0x4D` | Interrupt status 0 / 1 | R | `0x00` | Unused |
| `0x4F` | Output port configuration | R/W | `0x00` | Unused |

> [!note] Register pairs (§8.1, §8.2)
> Extra bytes in a transfer alternate between the two registers of a pair; they
> don't advance the address.
> - `[0x46, 0xFF, 0xFF]` sets both pull-enable registers.
> - A read at `0x00` returns `Input0, Input1, Input0, …`.
> - The pointer stays on the pair, so later polls can skip the command byte
>   (even byte counts only).

The input latch (§7.4.6) only helps with presses shorter than the 1 ms poll, so
it stays off.

## Firmware notes

### Startup sequence
1. Drive J3 pin 9 high (power hold, releases reset). trec(rst) is 200 ns, so
   I2C can start immediately.
2. Write `[0x46, 0xFF, 0xFF]` (enable pull-ups; select already defaults to up).
3. Optional: `[0x04, 0xFF, 0xFF]` so pressed reads as 1.
4. Read at `0x00` once to set the pointer, then poll every report cycle.

> [!warning] Inputs float until step 2
> Floating inputs read garbage and can draw up to 80 µA each (ΔIDD, Table 34).
> Do step 2 early; ignore reads before it.

### Polling cost
| Transaction | Bits | Time at 400 kHz |
|---|---|---|
| With command byte: `S addr+W 0x00 Sr addr+R d0 d1 P` | ~45 | ~115 µs |
| Pointer already set: `S addr+R d0 d1 P` | ~27 | ~70 µs |

### Current
- ~1 µA standby, ~40 µA while polling continuously.
- Each **held** button: 3.3 V / 100 kΩ ≈ **33 µA** (22–66 µA).
- Nothing when the controller is off (3.3 V rail down).

### Code

```c
#define PCAL6416_ADDR        0x21

#define PCAL_REG_INPUT0      0x00
#define PCAL_REG_POLARITY0   0x04
#define PCAL_REG_CONFIG0     0x06
#define PCAL_REG_PULL_EN0    0x46
#define PCAL_REG_PULL_SEL0   0x48

#define BTN_SHARE  (1u << 0)
#define BTN_X      (1u << 1)
#define BTN_Y      (1u << 3)
#define BTN_RB     (1u << 4)
#define BTN_LB     (1u << 5)
#define BTN_MENU   (1u << 7)
#define BTN_PAIR   (1u << 8)
#define BTN_DUP    (1u << 9)
#define BTN_DRIGHT (1u << 10)
#define BTN_DLEFT  (1u << 11)
#define BTN_DDOWN  (1u << 12)
#define BTN_VIEW   (1u << 13)
#define BTN_A      (1u << 15)
#define BTN_UNUSED_MASK ((1u << 2) | (1u << 6) | (1u << 14))

/* raw = Input0 | (Input1 << 8); active-low without polarity inversion */
static inline uint16_t pcal_buttons(uint16_t raw)
{
    return (uint16_t)(~raw) & (uint16_t)~BTN_UNUSED_MASK;
}
```

## To verify
- [x] Register map matches the datasheet.
- [ ] I2C scan finds `0x21`.
- [ ] Every button matches the map (probe the TPs or read over I2C).
- [ ] No I2C pull-ups on the top board; size ours.
- [ ] Current with pull-ups enabled, no buttons held.

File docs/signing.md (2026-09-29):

---
title: Firmware signing
created: 2026-09-29
updated: 2026-09-29
tags:
  - xbx-nrf
  - firmware
  - security
  - howto
aliases:
  - signing
  - MCUboot
---

# Firmware signing

Release builds: **MCUboot**, **ECDSA P-256**. MCUboot only boots or installs
images signed with the device's key. Related: [[docs/building]],
[[docs/flashing|Flashing & debugging]], [[todo#Firmware signing]].

## Keys

| Device | App | Key file |
|---|---|---|
| Controller | `firmware/xbx-nrf` | `~/.config/xbx-nrf/keys/controller-p256.pem` |
| Dongle | `firmware/dongle` | `~/.config/xbx-nrf/keys/dongle-p256.pem` |

- **One key per device type**, so MCUboot rejects dongle firmware on the
  controller and vice versa (it only checks the signer, not the image's
  purpose).
- Outside the repo (folder `700`, files `600`). `.gitignore` also blocks
  `*.pem`, `*.key`, `*.p12`, `*.pfx`, `*.der`, `keys/`.
- `XBX_KEY_DIR` is exported by `~/bin/ncs-shell` only.

> [!danger] Back up both keys offline
> A lost key means those devices can only be updated over SWD.

> [!warning] Never sign with the default key
> Without `SB_CONFIG_BOOT_SIGNATURE_KEY_FILE`, the SDK silently signs with
> MCUboot's **public demo key** (`root-ec-p256.pem`) or a generated
> `GENERATED_NON_SECURE_SIGN_KEY_PRIVATE.pem`. `build-signed.sh` refuses to run
> without our key.

### Generating a key (done 2026-09-29)
```sh
umask 077; mkdir -p ~/.config/xbx-nrf/keys
python3 ~/ncs/v3.4.1/bootloader/mcuboot/scripts/imgtool.py keygen \
    -k ~/.config/xbx-nrf/keys/controller-p256.pem -t ecdsa-p256
```

## Building a signed release

```sh
ncs-shell
cd ~/Projects/xbx-nrf
firmware/build-signed.sh dongle nrf52840dongle/nrf52840/bare
firmware/build-signed.sh xbx-nrf <custom-board>   # once it exists
```

The script picks the app's key from `$XBX_KEY_DIR`, builds with
`sysbuild-signed.conf` into `<app>/build-signed/`, and passes the key path on
the command line (nothing committed). Development builds and the Pro Micro
prototypes don't use MCUboot.

### Outputs (`<app>/build-signed/`)

| File | Use |
|---|---|
| `<app>/zephyr/zephyr.signed.bin` | Update image (serial recovery / mcumgr) |
| `<app>/zephyr/zephyr.signed.hex` | Signed application, hex |
| `dfu_application.zip` | Update package (nRF Connect tools) |

First install (MCUboot + app) over SWD: `west flash -d <app>/build-signed`.

### Verifying a signature
```sh
python3 ~/ncs/v3.4.1/bootloader/mcuboot/scripts/imgtool.py verify \
    -k ~/.config/xbx-nrf/keys/dongle-p256.pem \
    firmware/dongle/build-signed/dongle/zephyr/zephyr.signed.bin
```
"Image was correctly validated" = signed with that key. Tested 2026-09-29:
accepted by the dongle key, rejected by the controller and demo keys.

## Installing updates (to decide)

- **MCUboot serial recovery over USB** (planned): hold a button at power-up,
  upload with `mcumgr` / `smpmgr`. Needs MCUboot config (serial recovery, CDC
  ACM, entry button).
- Over the radio: possible later, custom work.

## Limits

> [!important] Useless unless SWD is locked
> With the debug port open, anyone can replace MCUboot. Release devices need
> **APPROTECT**; development boards stay unlocked
> ([[docs/flashing#Locked chip (APPROTECT)]]).

- Signed, not encrypted.
- Image version comes from the app's `VERSION` file (`0.1.0+0`;
  [[docs/building#Versions]]). Downgrade protection isn't enabled yet.

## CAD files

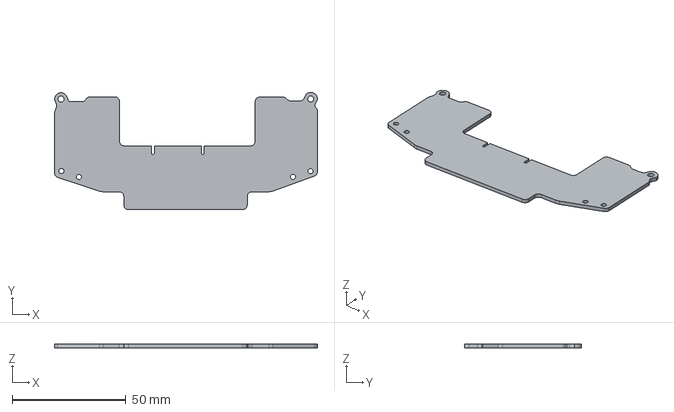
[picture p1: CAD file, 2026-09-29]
references/pcb-cad-pcb.step
115.8 x 51.7 x 1.60 mm

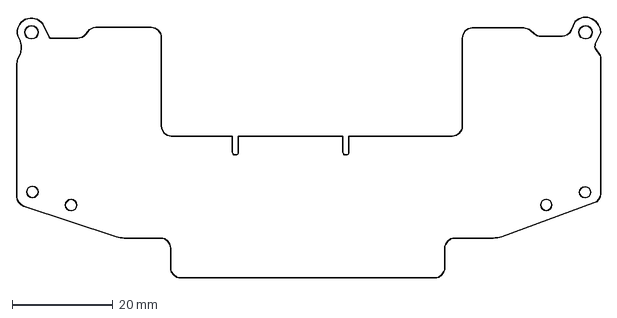
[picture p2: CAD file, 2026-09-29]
references/pcb-cad-pcbSketch.dxf
116.1 x 52.0 mm

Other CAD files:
references/pcb-cad.FCStd

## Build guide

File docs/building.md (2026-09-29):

---
title: Building the firmware
created: 2026-09-29
updated: 2026-09-29
tags:
  - xbx-nrf
  - firmware
  - howto
aliases:
  - building
  - build
  - versions
---

# Building the firmware

Related: [[docs/flashing|Flashing & debugging]],
[[docs/signing|Firmware signing]], [[todo#5. Firmware]].

## Apps

| App | Folder | Default board (for now) | Later |
|---|---|---|---|
| Controller | `firmware/xbx-nrf` | `promicro_nrf52840/nrf52840/uf2` | Custom board definition |
| Dongle | `firmware/dongle` | `promicro_nrf52840/nrf52840/uf2` | `nrf52840dongle/nrf52840` |

Standalone Zephyr apps, outside the SDK folder. Shared code:
`firmware/common/include/` (e.g. `protocol.h`).

## Pinned versions

| Component | Version | Pinned where |
|---|---|---|
| nRF Connect SDK | **v3.4.1** (LTS) | `firmware/ncs-version` |
| Toolchain bundle | **8285d8ad56** | `firmware/ncs-version` |
| Zephyr | 4.4.2 | part of the SDK |
| nrfutil / sdk-manager | 8.2.1 / 1.16.1 | not pinned |
| KiCad | 10.0.3 | not pinned |

`firmware/check-sdk.sh` (run by both build scripts) stops the build if
`$ZEPHYR_BASE/../nrf/VERSION` or the toolchain behind `west` doesn't match
`firmware/ncs-version`, and prints the fix.

## Setup

1. Install `nrfutil`, then the SDK and toolchain (into `~/ncs/`):
   ```sh
   nrfutil install sdk-manager
   nrfutil sdk-manager install --ncs-version v3.4.1
   ```
2. Create `~/bin/ncs-shell` (not in the repo):
   ```bash
   #!/bin/bash
   export XBX_KEY_DIR="$HOME/.config/xbx-nrf/keys"   # docs/signing.md
   export ZEPHYR_BASE="$HOME/ncs/v3.4.1/zephyr"
   nrfutil sdk-manager toolchain launch --ncs-version v3.4.1 --shell
   ```
   `ZEPHYR_BASE` lets `west build` work from our app folders; without it west
   reports "unknown command build".
3. USB permissions: see [[docs/flashing]].

## Building

Development builds: unsigned, no bootloader, into `<app>/build/`.

```sh
ncs-shell
cd ~/Projects/xbx-nrf
firmware/build-unsigned.sh xbx-nrf       # incremental
firmware/build-unsigned.sh dongle -p     # pristine
firmware/build-unsigned.sh dongle -p -b nrf52840dongle/nrf52840
```

- Extra arguments go to `west build`; `-b` overrides the default board.
- Default boards live in `build-unsigned.sh`; update them when the real hardware
  exists ([[todo#Link]]).
- Plain `west build` also works but skips the version check, and needs `-b`
  again after `-p`.

Signed builds: [[docs/signing]].

### Output files

Sysbuild puts each image in a subfolder named after the app:

| File | Use |
|---|---|
| `<app>/build/<app>/zephyr/zephyr.uf2` | UF2 bootloader (Pro Micro) |
| `<app>/build/<app>/zephyr/zephyr.hex` | SWD flashing |
| `<app>/build/<app>/zephyr/zephyr.elf` | Debugging |

`<app>/build/zephyr/` is sysbuild's own and has no firmware.

### Board overlays

Name them after the **full** board target, `/` → `_`:

| Board target | Overlay file |
|---|---|
| `promicro_nrf52840/nrf52840/uf2` | `promicro_nrf52840_nrf52840_uf2.overlay` |
| `nrf52840dongle/nrf52840` | `nrf52840dongle_nrf52840.overlay` |

Shorter names are **silently ignored**; look for `-- Found devicetree overlay:`
in the build log.

### Default board: why it's in the script

Sysbuild resolves the board before reading the app, so `set(BOARD …)` in an
app's `CMakeLists.txt` has no effect.

## Versions

| What | Where | Bump when |
|---|---|---|
| **App version** | `<app>/VERSION` | Releasing that app |
| **Protocol version** | `XBX_PROTOCOL_VERSION` in `protocol.h` | Packet format changes; reflash **both** boards |
| **Build ID** | `git describe` (`APP_BUILD_VERSION`) | Automatic |

- Printed at boot, e.g.
  `xbx-nrf controller v0.1.0 (47bdc2425afb), protocol v1, channel 76, tx 8 dBm`.
- After `git tag v0.1.0` the build ID reads `v0.1.0` (`v0.1.0-3-g<hash>` later).
- Uncommitted changes don't show in the build ID: commit before flashing
  anything you keep.
- Signed images carry the app version (`0.1.0+0`) for MCUboot.

## Upgrading the SDK

1. Read Nordic's release notes and migration guide.
2. `nrfutil sdk-manager install --ncs-version <new>`; note the toolchain bundle
   ID (`~/ncs/toolchains/toolchains.json`).
3. Update `firmware/ncs-version`, `~/bin/ncs-shell` and the table above.
4. Pristine-build both apps, unsigned and signed; fix warnings.
5. Re-run the link test on hardware.
6. Commit it all together ("Upgrade to NCS vX.Y.Z").

Older SDKs can stay installed side by side for building old commits.

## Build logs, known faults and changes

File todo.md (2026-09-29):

---
title: xbx-nrf TODO
created: 2026-09-28
updated: 2026-09-29
tags:
  - xbx-nrf
  - todo
---

# xbx-nrf TODO

Locked decisions: [README](README.md). Not yet locked:

> [!info] Working assumptions
> - **Antenna:** reuse the stock Xbox antennas via coax + matching network, if
>   they check out ([[#MCU / radio]]).
> - **Power switching:** stock top board latch; our board holds it via J3 pin 9
>   ([[docs/hardware]]).

## References

- Schematics: [[references/XB1 1914 TOP BOARD.pdf]],
  [[references/XB1_1914_BOTTOM_BOARD_SOME_VALUES.pdf]],
  [[references/XB1_1914_SOC_SOME_VALUES.pdf]]
- Pinouts: [[references/controller-pinouts.txt]],
  [[references/soc-pinout.txt]]
- Notes: [[docs/hardware|Hardware]], [[docs/pcal6416|PCAL6416]],
  [[docs/a3910|A3910]], [[docs/protocol|Protocols]], [[docs/gip|GIP]],
  [[docs/building|Building]], [[docs/flashing|Flashing]],
  [[docs/signing|Signing]]
- Datasheets: [[references/A1304-Datasheet.pdf]] (trigger sensor, 7.7 mA,
  t_PO 50–70 µs), [[references/A3910-datasheet.pdf]],
  [[references/PCAL6416A-datasheet.pdf]]
- Outline: [[references/pcb-cad.FCStd]], [[references/pcb-cad-pcbSketch.dxf]];
  KiCad: `pcb/xbx-nrf/`

---

## 1. Verify / reverse-engineer (stock hardware)

### Power latch (top board)

> [!note] Current reading
> - **Guide** (SW13 → Q8) or **Pair** (SW2 → R46 → Q14) drives Q9 → Q6/Q7 →
>   `3v/B+` → boosts.
> - **Hold:** J3 pin 9 → R7 → D26 → Q9; same net as the
>   [[docs/pcal6416#Connections|PCAL6416 reset]].
> - Probably **not self-holding**: firmware must raise pin 9 before release.
> - **J3 pin 13** (via D30) is probably Pair sense, not a force-off input.

- [x] R46 → SW2 Pair / PCAL6416 P10 net (Pair power-on path).
- [ ] Bench test: bottom board out, 2.0–2.8 V on the AA wires, watch TP35:
	- [ ] Guide press: does 3.3 V drop on release?
	- [ ] Same with Pair.
	- [ ] How long does power stay up while held (boot-to-hold budget)?
	- [ ] Pin 9 pulled high (1 kΩ to 3.3 V) keeps power after release; letting
	      go of pin 9 turns it off.
- [ ] Trace R25's source.
- [ ] Q8 and Q14 polarity (PNP expected).
- [ ] Pin 9 holds power *and* resets the PCAL6416 (R4/EG2).
- [ ] Pin 13 reads low while Pair is pressed (with a pull-up).
- [ ] How the stock SoC powers off (pin 9 release only?).
- [ ] Standby current from the AAs, controller off.
- [ ] USB plugged in: U1 powers `3v/B+` regardless of the latch; Q6 isolates the
      AAs.

### J3/J5 connector (top ↔ bottom)
- [ ] Connector part number and pitch; source the mating half.
- [ ] Full pinout vs. schematic:
	- [ ] Pin 11: SoC pin 1 / J7 pin 1. Play & Charge?
	- [ ] Pin 13: SoC pin 10, probably Pair sense.
- [ ] Pin 2 (Guide) active-low, pull-up on our side.
- [ ] 3.3 V / 3.6 V / `3v/B+` on J3, controller on vs off.

### PCAL6416 expander (top board)
[[docs/pcal6416|PCAL6416 notes]]
- [x] Port → button map ([[docs/pcal6416#Port → button map]]).
- [x] INT not connected → poll.
- [x] Register map checked against the datasheet
      ([[docs/pcal6416#Register map]]).
- [ ] I2C scan finds `0x21`.
- [ ] Where are the I2C pull-ups?
- [ ] Every button on real hardware.

### Bottom board (being replaced)
- [x] Sticks are on the bottom board.
- [x] Stick footprint: Alps **RKJXV122400R** (SnapMagic), in
      `pcb/xbx-nrf/lib/RKJXV122400R/`; pads checked against
      [[references/product_catalog_rkjxv.pdf]].
- [ ] Stock sticks really are RKJXV122400R (calipers or 1:1 print).
- [ ] Each stick's rotation (which pot is X/Y, axis direction).
- [ ] Push-switch contact pairs (A/B/C/D).
- [ ] A1304 placement relative to the trigger magnets.
- [ ] Stick supply `AN+`: U6 TLV70718 (1.8 V LDO with enable).
- [ ] Trigger sensor supply `TRG+`: pulsed, 125 Hz, 17 % duty.
- [x] Rumble drivers: 2× A3910 (U4: LT + Heavy, U5: RT + Light)
      ([[docs/a3910#Stock wiring (bottom board)]]).
- [ ] Motor pad positions, VBB decoupling, CR1–CR4 parts
      ([[docs/a3910#To verify]]).
- [ ] Headset jack on this board? Position and footprint.
- [ ] **J7** (Play & Charge: VBUS / SDA2 / SCL2): footprint and position.
	- [ ] Sniff I2C2 with a pack: does it need commands to charge?
- [ ] **J8** (expansion port) pinout.
- [ ] Mounting holes, outline, keep-outs (calipers, from a datum hole).

---

## 2. Mechanical

- [ ] Fully constrained FreeCAD outline (datum hole at origin).
	- [ ] Check the image scale on a second horizontal and vertical distance
	      (X was ~4.9 % off).
	- [ ] Holes, J3, stick centers, trigger sensors, J7 from calipers.
- [ ] DXF → KiCad `Edge.Cuts`; holes → MountingHole footprints.
- [ ] 1:1 paper print fit check.
- [ ] STEP fit check in the shell.
- [ ] Trigger stops (independent of the side rails):
	- [ ] Blu-Tack clearance test behind each trigger.
	- [ ] Fixed stop / adjustable screw (non-magnetic) / modified triggers.
	- [ ] Click switches: hard stop within the switch's overtravel.

---

## 3. Hardware design — controller board

### Power (rechargeable AA)
- [ ] nRF on J3 3.3 V (VDD, normal voltage mode; max 3.6 V).
- [ ] Hold / off:
	- [ ] GPIO → J3 pin 9 (hold + expander reset); low at reset, raised early.
	- [ ] GPIO ← J3 pin 2 (Guide), pull-up.
	- [ ] GPIO ← J3 pin 13 (Pair), pull-up, if confirmed; readable while the
	      expander is in reset.
- [ ] Battery sense: switched ADC divider on `3v/B+` (J3 pin 3).
	- [ ] NiMH cutoff (~1.0 V/cell = 2.0 V) and warning threshold.
	- [ ] Flat NiMH curve → coarse gauge; maybe coulomb counting.
	- [ ] Regulated Li-ion AAs: no gauge possible.
- [ ] VBUS detect (J3 pin 12).
- [ ] **Charging:** external (default) / VBUS to J7 for Play & Charge / in
      controller (needs chemistry detection; probably not worth it).
- [ ] Stick supply: LDO with enable (like AN+) or load switch.
- [ ] Trigger sensor supply: switched, pulsed (on, ≥ 100 µs, sample, off).
- [ ] No back-powering: float GPIOs before a rail goes down.

### MCU / radio
- [x] MCU: **nRF52840** (no audio in v1).
- [ ] Module: pre-certified nRF52840 **with an RF pad or u.FL** (for the stock
      antennas); check its size.
- [ ] **Stock antennas: verify before ordering the PCB.** Top board: `ANT` (Z4,
      Z5, Z6 → J5/J6), `ANT1` (Z1, Z2, Z3 → J8). Stock SoC board: coax J1, J2.
      One was Xbox Wireless, one Bluetooth.
	- [ ] Which connector goes where; connector/cable type.
	- [ ] Find the **2.4 GHz** antenna (return loss). VNA: NanoVNA V2 / SAA-2N
	      (3 GHz) or LiteVNA 64 (6.3 GHz); NanoVNA-H/H4 only reach ~1.5 GHz.
	- [ ] Top board's matching network at 2.4 GHz.
	- [ ] Pi network on our board (3 footprints, VNA-tuned, 0 Ω bypass).
	- [ ] Fallback: chip-antenna module at the shell edge.
- [ ] Analog inputs: 8 on the nRF52840; 4 stick + 2 trigger + 1 battery = 7.
- [ ] RF layout: short 50 Ω CPW to the coax, ground vias, away from motors and
      battery wiring.
- [ ] SWD header / pads.
- [ ] USB D+/D− from J3 (90 Ω pair); ESD on the top board?

### Inputs
- [ ] Sticks: stock pots or TMR/Hall?
- [ ] Triggers: A1304 at the stock positions.
- [ ] I2C to the PCAL6416 + pull-ups ([[docs/pcal6416#Connections]]).
- [ ] B, LSC, RSC switches.

### Rumble
[[docs/a3910|A3910 notes]]
- [x] Stock wiring: 2× A3910, 8 GPIOs (LIN to GND on Heavy/Light frees 2).
- [ ] Schematic block ([[docs/a3910#Schematic checklist]]).
- [ ] A3910 symbol (draw, or `easyeda2kicad` C150818).
- [ ] Motor pads at the stock positions.

### Connectors
- [ ] J3 mating connector.
- [ ] J7 Play & Charge contacts (if used).
- [ ] J8 expansion port: keep or drop?

---

## 4. Hardware design — dongle

- [ ] Prototype on the PCA10059.
- [ ] Custom dongle PCB (optional, if the PCA10059 falls short).

---

## 5. Firmware

### Link
Code: `firmware/{xbx-nrf,dongle}/src/main.c`,
`firmware/common/include/protocol.h`. [[docs/building]], [[docs/flashing]].

> [!note] M1 results (2026-09-29, two Pro Micros)
> | Test | Result |
> |---|---|
> | Desk, 0 dBm | ~993/s (k_timer rounding), RSSI −46 dBm |
> | Desk, TIMER3 + seq fix | 1000/s, lost 0, RSSI −55 dBm; `failed` > 0 with `lost` 0 = lost ACKs only |
> | Across the room, 0 dBm | RSSI −79…−89 dBm, 0–65 % delivered |
> | Across the room, +8 dBm | RSSI −69…−74 dBm, 98–99.8 % delivered |
>
> Clone antennas are weak. Remaining loss looks like fades/interference →
> channel hopping.

- [ ] **Update the default boards in `build-unsigned.sh`** once real hardware
      exists (custom board; `nrf52840dongle/nrf52840`).
- [x] Test firmware: ESB 2 Mbps, 1 ms fake reports, ACK payloads, stats,
      P0.17 timing pin.
- [x] Report timing from hardware TIMER3 (exact 1 kHz; ESB uses TIMER2).
- [x] Sequence number advances only on sent reports; 16-bit (protocol v1,
      23-byte report); gap ≥ 0x8000 = restart.
- [x] TX power +8 dBm both ends (`XBX_TX_POWER_DBM`).
- [ ] Check controller `skipped` when the dongle shows `rx` < 1000 with low
      `lost` (seen once: `rx 942 lost 2`).
- [ ] If still marginal: 1 Mbps (+3–4 dB; recheck `RETRANSMIT_DELAY_US`).
- [ ] Latency on the scope (P0.17: controller high while in flight, dongle
      pulses on receive).
- [ ] Busy Wi-Fi, distance, other channels (`XBX_RF_CHANNEL`).
- [ ] Tune retransmit delay/count (min delay 435 µs → one retry per 1 ms).
- [ ] Dongle timing pin once usable PCA10059 pads are known.
- [x] Packet format v1 ([[docs/protocol#Radio (controller ↔ dongle)]]).
- [ ] Channel hopping (per-dongle sequence, driven by the TDMA schedule).

### Pairing & multiple controllers (protocol v2)
Design: [[docs/protocol#Pairing & multiple controllers (planned, protocol v2)]].
Up to 7 paired (least recently connected replaced), 4 connected; 1 kHz for
1–2, 500 Hz for 3–4.
- [ ] Per-dongle random address; pipe 0 = pairing, pipes 1–7 = controllers;
      pairing table in flash (settings).
- [ ] Pairing mode (Pair hold / dongle button / unpaired at plug-in), channel
      scan, PAIR_REQ/OFFER/CONFIRM/DONE (repeat until answered), RSSI check.
- [ ] Channel choice at first use (quietest of the candidate list).
- [ ] TDMA: dongle frame + slots, timing correction in ACKs, controller TIMER3
      trim; 1 ms / 2 ms frame switching.
- [ ] Join / full / drop handling; player number = slot.
- [ ] USB: 4 player interfaces (HID; XInput as Xbox 360 Wireless Receiver).
- [ ] Test: 2 controllers at 1 kHz (two Pro Micros + PCA10059), then 4 at 500
      Hz (more Pro Micro clones).
- [ ] Factory reset combo; error blinks (mismatch, ambiguity, full).
- [ ] Tune: pairing timeout, RSSI threshold, drop timeout.

### Dongle
USB modes, in order; one active at a time.
1. [ ] **HID gamepad** (Zephyr USB HID): 16-bit sticks, 10-bit triggers, all
       buttons, rumble output report. Draft layout:
       [[docs/protocol#USB HID mode (dongle ↔ PC), planned]].
2. [ ] **XInput** (custom class, after GP2040-CE): `045E:028E`, 8-bit
       triggers, 2 motors, no Share.
3. [ ] **Mode switching** at plug-in, stored in flash.

### Controller
- [ ] Power state machine: hold pin 9 early → PCAL6416 setup → run;
      long-press Guide / idle / no dongle / low battery → release hold.
- [ ] Boot reason: Guide / Pair (→ pairing) / USB.
- [ ] USB-powered "off" state.
- [ ] PCAL6416 polling ([[docs/pcal6416#Firmware notes]]).
- [ ] Stick/trigger ADC, trigger supply pulsed in sync.
- [ ] Trigger calibration + remapping (stops, hair trigger).
- [ ] Stick deadzones, calibration in flash.
- [ ] Rumble PWM ([[docs/a3910#Firmware notes]]).
- [ ] Battery monitoring, low-battery shutdown.
- [ ] Wired USB gamepad mode.

### Build & versions
[[docs/building|Building]]
- [x] SDK pinned in `firmware/ncs-version` (v3.4.1, toolchain 8285d8ad56),
      checked by the build scripts.
- [x] App `VERSION` files (0.1.0); boot log shows version, build ID, protocol.
- [ ] `git tag v0.1.0` once M1 is done.

### Firmware signing
[[docs/signing|Signing]]
- [x] One key per device, in `~/.config/xbx-nrf/keys/`.
- [x] `.gitignore` key patterns.
- [x] `sysbuild-signed.conf` + `build-signed.sh`; dongle build verified.
- [x] Image version from `VERSION` (`0.1.0+0`).
- [ ] **Back up both keys offline.**
- [ ] Update method: MCUboot serial recovery over USB (`mcumgr`/`smpmgr`).
- [ ] Downgrade protection.
- [ ] Release: lock APPROTECT.
- [ ] **MCUboot vs. power hold:** MCUboot runs before the app raises pin 9.
      Measure; if too slow, raise pin 9 from an MCUboot hook.

---

## 6. Prototyping milestones

- [ ] **M1:** 1 kHz link, latency and loss measured ([[#Link]]).
- [ ] **M2:** dongle works as HID, then XInput ([[#Dongle]]).
- [ ] **M2b:** pairing; 2 controllers at 1 kHz, then 4 at 500 Hz
      ([[#Pairing & multiple controllers (protocol v2)]]).
- [ ] **M3:** dev board on a stock top board via J3: buttons, Guide, power
      hold/off.
- [ ] **M4:** first custom board fits; inputs + rumble work.
- [ ] **M5:** battery life on NiMH AAs.
- [ ] **M6 (later):** Elite Series 2 port (broken 1797 donor, AcidMods scans).

---

## Future / v2

### Headset audio
- New board revision: codec (MAX9867 / WM8960 / NAU88C22), 3.5 mm jack with
  plug detect.
- Consider the **nRF5340** then (audio clock, dual core); **not pin-compatible**
  with the nRF52840. On the nRF52840, I2S plus a software resampler.
- Firmware: USB Audio Class; mic first, then ADPCM, then LC3; drift
  compensation, jitter buffer, loss concealment.

### Dynamic TX power
- +8 dBm costs battery at 1 kHz. Dongle sends RSSI back in the ACK payload;
  controller steps power down while strong, up fast on weak RSSI or lost ACKs
  (with hysteresis). Dongle does the same for ACKs.
- Decide after real-hardware link margin and M5.

### Trigger rumble (controller-side)
Games rarely drive the trigger motors, and XInput can't (2 motors only).
- **Rumble mixing:** feed part of the heavy/light rumble into the trigger
  motors when the host sends only 2 values. Configurable strength.
- **Local trigger effects:** click when a trigger crosses a threshold, buzz at a
  trigger stop; generated on the controller, pairs with hair-trigger mode.
- **4-value HID output report** for our own tools (and maybe Steam later).

### GIP dongle mode
Optional third USB mode speaking Microsoft's protocol ([[docs/gip]]). Gains:
impulse triggers in Windows games that use them, native Share, 10-bit triggers.
Feasible (no auth on PC via the opt-out GUID; GP2040-CE as reference), but
metadata needs Microsoft's compiler, and on Linux `xpad` drops trigger rumble.
- [ ] **Test first:** genuine Series controller over USB, SDL `testcontroller`
      trigger rumble, with and without Steam, on Linux. No buzz → GIP isn't
      worth it on Linux.
- [ ] Get the "gipdocs" download (metadata compiler, gamepad JSON template).
- [ ] Decide VID/PID (Microsoft's for `xpad` auto-binding, or bind manually).

---

## Open questions

- Is the latch self-holding (expected: no)?
- Is J3 pin 13 Pair sense? What is pin 11?
- Does a Play & Charge pack need I2C commands to charge?
- Stock stick pots or TMR?

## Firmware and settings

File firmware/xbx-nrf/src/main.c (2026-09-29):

/*
 * xbx-nrf controller firmware.
 *
 * M1 link test: sends a fake input report every 1 ms over ESB (PTX) and
 * prints link statistics once per second. The dongle replies with an output
 * report in the ACK payload.
 */

#include <zephyr/kernel.h>
#include <zephyr/drivers/counter.h>
#include <zephyr/drivers/gpio.h>
#include <zephyr/logging/log.h>
#include <esb.h>

#include <string.h>

#include <app_version.h>

#include "protocol.h"

LOG_MODULE_REGISTER(ctrl, LOG_LEVEL_INF);

/* One retry fits in a 1 ms frame (ESB minimum retransmit delay is 435 us). */
#define RETRANSMIT_DELAY_US 450
#define RETRANSMIT_COUNT    1

/* Report timing comes from a hardware timer: the 32768 Hz system tick can't do an
 * exact 1 ms (k_timer rounds to 33 ticks = 1.007 ms, ~993 reports/s).
 * TIMER2 is used by ESB.
 */
static const struct device *const report_counter = DEVICE_DT_GET(DT_NODELABEL(timer3));

#define ZEPHYR_USER DT_PATH(zephyr_user)
#if DT_NODE_HAS_PROP(ZEPHYR_USER, timing_gpios)
static const struct gpio_dt_spec timing_pin = GPIO_DT_SPEC_GET(ZEPHYR_USER, timing_gpios);
#define HAS_TIMING_PIN 1
#else
#define HAS_TIMING_PIN 0
#endif

struct link_stats {
	uint32_t sent;
	uint32_t ok;
	uint32_t failed;
	uint32_t attempts;
	uint32_t skipped; /* tick arrived while the previous report was still in flight */
	uint32_t acks_with_payload;
};

static struct link_stats stats;
static atomic_t in_flight;
static struct xbx_output_report last_output;

static K_SEM_DEFINE(tick_sem, 0, 1);

static void timing_pin_set(int value)
{
#if HAS_TIMING_PIN
	gpio_pin_set_dt(&timing_pin, value);
#endif
}

static void radio_event_handler(struct esb_evt const *event)
{
	struct esb_payload rx;

	switch (event->evt_id) {
	case ESB_EVENT_TX_SUCCESS:
		stats.ok++;
		stats.attempts += event->tx_attempts;
		timing_pin_set(0);
		atomic_set(&in_flight, 0);
		break;
	case ESB_EVENT_TX_FAILED:
		stats.failed++;
		stats.attempts += event->tx_attempts;
		timing_pin_set(0);
		atomic_set(&in_flight, 0);
		break;
	case ESB_EVENT_RX_RECEIVED:
		/* ACK payloads from the dongle */
		while (esb_read_rx_payload(&rx) == 0) {
			if (rx.length == sizeof(struct xbx_output_report) &&
			    rx.data[0] == XBX_MSG_OUTPUT) {
				memcpy(&last_output, rx.data, sizeof(last_output));
				stats.acks_with_payload++;
			}
		}
		break;
	default:
		break;
	}
}

static int radio_init(void)
{
	static const uint8_t base_addr_0[4] = XBX_BASE_ADDR_0;
	static const uint8_t base_addr_1[4] = XBX_BASE_ADDR_1;
	static const uint8_t prefixes[] = XBX_ADDR_PREFIXES;
	struct esb_config config = ESB_DEFAULT_CONFIG;
	int err;

	config.mode = ESB_MODE_PTX;
	config.protocol = ESB_PROTOCOL_ESB_DPL;
	config.bitrate = ESB_BITRATE_2MBPS;
	config.retransmit_delay = RETRANSMIT_DELAY_US;
	config.retransmit_count = RETRANSMIT_COUNT;
	config.tx_output_power = XBX_TX_POWER_DBM;
	config.use_fast_ramp_up = true;
	config.selective_auto_ack = true;
	config.event_handler = radio_event_handler;

	err = esb_init(&config);
	if (err) {
		return err;
	}
	err = esb_set_base_address_0(base_addr_0);
	if (err) {
		return err;
	}
	err = esb_set_base_address_1(base_addr_1);
	if (err) {
		return err;
	}
	err = esb_set_prefixes(prefixes, ARRAY_SIZE(prefixes));
	if (err) {
		return err;
	}
	return esb_set_rf_channel(XBX_RF_CHANNEL);
}

/* Fake input for the link test: sticks sweep slowly, A toggles every 500 ms. */
static void fill_fake_input(struct xbx_input_report *report, uint32_t tick, uint16_t seq)
{
	int16_t sweep = (int16_t)((tick * 64u) & 0xFFFF);

	memset(report, 0, sizeof(*report));
	report->type = XBX_MSG_INPUT;
	report->seq = seq;
	report->buttons = ((tick / 500u) & 1u) ? XBX_BTN_A : 0;
	report->lx = sweep;
	report->ly = -sweep;
	report->rx = sweep / 2;
	report->ry = -sweep / 2;
	report->lt = (tick >> 2) & 0x3FF;
	report->rt = 0x3FF - ((tick >> 2) & 0x3FF);
	report->battery = 0xFF;
	report->timestamp_us = k_cyc_to_us_floor32(k_cycle_get_32());
}

static void report_tick(const struct device *dev, void *user_data)
{
	ARG_UNUSED(dev);
	ARG_UNUSED(user_data);
	k_sem_give(&tick_sem);
}

static int report_timer_start(void)
{
	struct counter_top_cfg top = {
		.ticks = counter_us_to_ticks(report_counter, XBX_REPORT_PERIOD_US),
		.callback = report_tick,
		.user_data = NULL,
		.flags = 0,
	};
	int err;

	if (!device_is_ready(report_counter)) {
		return -ENODEV;
	}
	err = counter_set_top_value(report_counter, &top);
	if (err) {
		return err;
	}
	return counter_start(report_counter);
}

static void tx_thread(void *p1, void *p2, void *p3)
{
	struct esb_payload tx = {
		.pipe = 0,
		.noack = false,
		.length = sizeof(struct xbx_input_report),
	};
	uint32_t tick = 0;
	uint16_t seq = 0; /* only advances when a report is actually sent */

	while (true) {
		k_sem_take(&tick_sem, K_FOREVER);
		tick++;

		if (atomic_get(&in_flight)) {
			stats.skipped++;
			continue;
		}

		/* drop anything stale (e.g. a report left behind after TX_FAILED) */
		esb_flush_tx();

		fill_fake_input((struct xbx_input_report *)tx.data, tick, seq);

		atomic_set(&in_flight, 1);
		timing_pin_set(1);
		if (esb_write_payload(&tx) == 0) {
			stats.sent++;
			seq++;
		} else {
			timing_pin_set(0);
			atomic_set(&in_flight, 0);
		}
	}
}

K_THREAD_DEFINE(tx_tid, 1024, tx_thread, NULL, NULL, NULL, K_PRIO_COOP(2), 0, 0);

int main(void)
{
	struct link_stats prev = {0};
	int err;

	LOG_INF("xbx-nrf controller v%s (%s), protocol v%d, channel %d, tx %d dBm",
		APP_VERSION_STRING, STRINGIFY(APP_BUILD_VERSION), XBX_PROTOCOL_VERSION, XBX_RF_CHANNEL,
		XBX_TX_POWER_DBM);

#if HAS_TIMING_PIN
	if (gpio_is_ready_dt(&timing_pin)) {
		gpio_pin_configure_dt(&timing_pin, GPIO_OUTPUT_INACTIVE);
	}
#endif

	err = radio_init();
	if (err) {
		LOG_ERR("ESB init failed: %d", err);
		return 0;
	}

	err = report_timer_start();
	if (err) {
		LOG_ERR("report timer start failed: %d", err);
		return 0;
	}

	while (true) {
		k_sleep(K_SECONDS(1));

		struct link_stats now = stats;
		uint32_t sent = now.sent - prev.sent;
		uint32_t ok = now.ok - prev.ok;
		uint32_t failed = now.failed - prev.failed;
		uint32_t attempts = now.attempts - prev.attempts;
		uint32_t done = ok + failed;

		LOG_INF("sent %u/s  ok %u  failed %u  skipped %u  avg attempts %u.%02u  acks %u  "
			"rumble[%u %u %u %u]",
			sent, ok, failed, now.skipped - prev.skipped,
			done ? attempts / done : 0, done ? (attempts * 100 / done) % 100 : 0,
			now.acks_with_payload - prev.acks_with_payload,
			last_output.rumble[0], last_output.rumble[1], last_output.rumble[2],
			last_output.rumble[3]);
		prev = now;
	}
	return 0;
}

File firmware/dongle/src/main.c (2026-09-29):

/*
 * xbx-nrf dongle firmware.
 *
 * M1 link test: receives input reports over ESB (PRX), answers each one with
 * an output report in the ACK payload, and prints link statistics once per
 * second. USB gamepad output (XInput/HID) comes in M2.
 */

#include <zephyr/kernel.h>
#include <zephyr/drivers/gpio.h>
#include <zephyr/logging/log.h>
#include <esb.h>

#include <string.h>

#include <app_version.h>

#include "protocol.h"

LOG_MODULE_REGISTER(dongle, LOG_LEVEL_INF);

#define ZEPHYR_USER DT_PATH(zephyr_user)
#if DT_NODE_HAS_PROP(ZEPHYR_USER, timing_gpios)
static const struct gpio_dt_spec timing_pin = GPIO_DT_SPEC_GET(ZEPHYR_USER, timing_gpios);
#define HAS_TIMING_PIN 1
#else
#define HAS_TIMING_PIN 0
#endif

struct link_stats {
	uint32_t received;
	uint32_t lost;       /* gaps in the input report sequence numbers */
	uint32_t bad;        /* wrong length or type */
	int32_t rssi_sum;
	uint32_t ack_queue_full;
};

static struct link_stats stats;
static struct xbx_input_report last_input;
static bool have_seq;
static uint16_t expected_seq;
static uint8_t output_seq;

static void timing_pin_set(int value)
{
#if HAS_TIMING_PIN
	gpio_pin_set_dt(&timing_pin, value);
#endif
}

/* Keep one output report queued as the ACK payload for the next received packet. */
static void queue_ack_payload(void)
{
	struct esb_payload ack = {
		.pipe = 0,
		.length = sizeof(struct xbx_output_report),
	};
	struct xbx_output_report *out = (struct xbx_output_report *)ack.data;

	if (esb_tx_full()) {
		stats.ack_queue_full++;
		return;
	}

	memset(out, 0, sizeof(*out));
	out->type = XBX_MSG_OUTPUT;
	out->seq = output_seq++;
	/* fake rumble for the link test: follow the controller's trigger values */
	out->rumble[XBX_RUMBLE_LT] = last_input.lt >> 2;
	out->rumble[XBX_RUMBLE_RT] = last_input.rt >> 2;

	esb_write_payload(&ack);
}

static void handle_input(const struct esb_payload *rx)
{
	const struct xbx_input_report *in = (const struct xbx_input_report *)rx->data;

	if (rx->length != sizeof(struct xbx_input_report) || in->type != XBX_MSG_INPUT) {
		stats.bad++;
		return;
	}

	if (have_seq) {
		uint16_t gap = (uint16_t)(in->seq - expected_seq);

		/* a huge gap means the controller restarted (sequence back near 0), not ~65k losses */
		if (gap < 0x8000) {
			stats.lost += gap;
		}
	}
	expected_seq = in->seq + 1;
	have_seq = true;

	stats.received++;
	stats.rssi_sum += rx->rssi;
	memcpy(&last_input, in, sizeof(last_input));
}

static void radio_event_handler(struct esb_evt const *event)
{
	struct esb_payload rx;

	if (event->evt_id != ESB_EVENT_RX_RECEIVED) {
		return;
	}

	timing_pin_set(1);
	while (esb_read_rx_payload(&rx) == 0) {
		handle_input(&rx);
		queue_ack_payload();
	}
	timing_pin_set(0);
}

static int radio_init(void)
{
	static const uint8_t base_addr_0[4] = XBX_BASE_ADDR_0;
	static const uint8_t base_addr_1[4] = XBX_BASE_ADDR_1;
	static const uint8_t prefixes[] = XBX_ADDR_PREFIXES;
	struct esb_config config = ESB_DEFAULT_CONFIG;
	int err;

	config.mode = ESB_MODE_PRX;
	config.protocol = ESB_PROTOCOL_ESB_DPL;
	config.bitrate = ESB_BITRATE_2MBPS;
	config.tx_output_power = XBX_TX_POWER_DBM;
	config.use_fast_ramp_up = true;
	config.selective_auto_ack = true;
	config.event_handler = radio_event_handler;

	err = esb_init(&config);
	if (err) {
		return err;
	}
	err = esb_set_base_address_0(base_addr_0);
	if (err) {
		return err;
	}
	err = esb_set_base_address_1(base_addr_1);
	if (err) {
		return err;
	}
	err = esb_set_prefixes(prefixes, ARRAY_SIZE(prefixes));
	if (err) {
		return err;
	}
	return esb_set_rf_channel(XBX_RF_CHANNEL);
}

int main(void)
{
	struct link_stats prev = {0};
	int err;

	LOG_INF("xbx-nrf dongle v%s (%s), protocol v%d, channel %d, tx %d dBm",
		APP_VERSION_STRING, STRINGIFY(APP_BUILD_VERSION), XBX_PROTOCOL_VERSION, XBX_RF_CHANNEL,
		XBX_TX_POWER_DBM);

#if HAS_TIMING_PIN
	if (gpio_is_ready_dt(&timing_pin)) {
		gpio_pin_configure_dt(&timing_pin, GPIO_OUTPUT_INACTIVE);
	}
#endif

	err = radio_init();
	if (err) {
		LOG_ERR("ESB init failed: %d", err);
		return 0;
	}

	queue_ack_payload();

	err = esb_start_rx();
	if (err) {
		LOG_ERR("ESB start RX failed: %d", err);
		return 0;
	}

	while (true) {
		k_sleep(K_SECONDS(1));

		struct link_stats now = stats;
		struct xbx_input_report in = last_input;
		uint32_t received = now.received - prev.received;
		int32_t rssi = received ? (now.rssi_sum - prev.rssi_sum) / (int32_t)received : 0;

		/* ESB reports RSSI as a positive magnitude in dBm */
		LOG_INF("rx %u/s  lost %u  bad %u  ack-full %u  rssi -%d dBm  | btn %04x "
			"L(%d,%d) R(%d,%d) LT %u RT %u",
			received, now.lost - prev.lost, now.bad - prev.bad,
			now.ack_queue_full - prev.ack_queue_full, rssi, in.buttons, in.lx, in.ly,
			in.rx, in.ry, in.lt, in.rt);
		prev = now;
	}
	return 0;
}

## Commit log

2026-09-29 Add xbx-nrf kicad project
    [xbx-nrf.kicad_pcb, xbx-nrf.kicad_sch]
2026-09-29 Add PCB and component references
    [pcb-cad-pcb.step, pcb-cad-pcbSketch.dxf, pcb-cad.FCStd]
2026-09-29 Add dongle USB device with pid.codes test IDs
2026-09-29 Forward HID rumble and LED to the controller
2026-09-30 Add breadboard GPIO input and rumble LEDs to the controller
2026-09-30 Add test-rumble tool with motor and level arguments
2026-09-30 Add HID PID force feedback descriptor and effect table
2026-09-30 Add PID effect engine and rumble mixing
2026-09-30 Document HID PID force feedback
2026-09-30 Add XInput receiver USB class and mode strap
2026-09-30 Forward radio input to XInput slot 0
2026-09-30 Forward XInput rumble and LED to the controller
2026-09-30 Plan TMR sticks and stick calibration
2026-09-30 Store stick calibration in flash
2026-09-30 Add on-device stick calibration routine
2026-09-30 Plan wired USB mode
2026-09-30 Share HID gamepad and PID code between apps
2026-09-30 Add controller USB device for wired mode
2026-09-30 Switch the controller to wired mode while a USB host is active
2026-09-30 Choose the wired USB mode at boot with X or B
2026-09-30 Add wired XInput mode to the controller
2026-09-30 Document controller wired USB mode
2026-10-01 Add dongle PCB schematic
2026-10-01 Document the dongle board pin map
2026-10-02 Support the nRF52840 Dongle (PCA10059) as the dongle board
2026-10-02 Update smd pad webbing on footprint
2026-10-02 Change board shape, reposition components. Pre-routing commit
2026-10-02 Dongle PCB Rev1 complete
2026-10-02 Attribute the dongle project footprint library
2026-10-02 Add title and date to dongle PCB sheets
2026-10-02 Add the custom dongle board definition
2026-10-02 Clean up silkscreen labels on dongle PCB
2026-10-02 Add JP1 silkscreen warning for dongle PCB
2026-10-02 Drive dongle LEDs open-drain and warn about JP1
2026-10-02 Move the bottom board outline to mech/
2026-10-02 Dongle PCB Rev1.1 ready for fab
2026-10-03 Time slots: sync controllers to the dongle's frame (protocol v2)
2026-10-03 Join, full flag and 2 ms frame for 3-4 controllers
2026-10-03 Dongle board: swap debug UART pins to match the schematic
2026-10-03 Update todo: dongle hardware, antennas and link items done
2026-10-03 Todo: three controllers at 500 Hz tested
2026-10-03 Move design plot markings to user layer for dongle pcb
2026-10-05 Todo: four controllers at 500 Hz tested
2026-10-05 Fully constrain the controller board outline
2026-10-05 Controller board: module core, debug headers and mounting holes
2026-10-05 Docs: teardown measurements, sensor supplies and A1304 notes
2026-10-05 Docs: PCAL6416 buttons and pin 9 reset verified
2026-10-05 Docs: latch transistors, Guide and I2C pull-ups checked
2026-10-06 Docs: J3/J5 connector geometry and footprint
2026-10-06 Docs: per-channel ADC settings, battery sense without divider
2026-10-06 Docs: P-FET for the trigger supply
2026-10-06 Rename the light rumble motor to weak
2026-10-07 Docs: J3 pin 11 battery status, latch values, P&C and spring todos
2026-10-07 Dongle PCB: add top render, KiCad re-save
2026-10-07 Controller schematic complete, layout pending
2026-10-07 Docs: layout measurement checklist for the stock bottom board
2026-10-10 Pre-rework of pcb outline constraints
2026-10-12 R1.1 bottom pcb outline completed. Pre: trace routing commit
2026-10-12 Remove old PCB outline
2026-10-13 Docs: Rev1.1 controller pins, layout measured, no Play & Charge in v1
2026-10-13 Rev 1.1 controller PCB outline complete
2026-10-13 PCBs staged for ordering Rev 1.1
2026-10-13 Controller Rev1.1: restore GND stitching vias
2026-10-13 Controller Rev1.1: 0.3 mm via holes to avoid JLC's small-via fee
2026-10-28 Controller board: bring-up board definition with fake input
2026-10-30 Controller: Guide LED solid while linked, slow blink while searching
2026-10-30 Controller board: PCAL6416 and GPIO buttons
2026-10-30 Fix: report timer stalls for minutes after a late tick
2026-10-30 Controller board: sticks and analog triggers
2026-10-30 Controller board: rumble motors on A3910 drivers
2026-10-30 Controller board: power off with a 6 s Guide hold
2026-10-30 Controller board: battery level and low-battery power-off
2026-10-30 Todo: controller power-off and battery monitoring
2026-10-30 Power off on idle, no dongle, or the PC's request
2026-10-30 Todo: auto power-off and power-off from the PC
2026-10-30 AUX inputs: paddles and trigger switches
2026-10-30 Docs: controller board target, SWD flashing, button pull-ups
2026-10-30 Todo: LT motor fixed, M4 done
2026-10-30 Battery: NiMH curve, read between rumbles, no rumble below 25 %
2026-10-30 Todo: battery curve and cutoffs
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2026-10-30 Todo: battery on the PC, SDL battery support open
2026-10-30 Rumble: 40 ms brake, 0 ms means coast
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2026-10-31 Todo: custom dongle first flash, LEDs, pair fixes
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2026-10-31 Configurator: stream, calibration, rumble and factory reset
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2026-10-31 Build: two targets per app, drop unused boards and options
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2026-10-31 Todo, docs: tick finished items, fix stale build and board details
2026-11-01 Controller: send from the timer, read inputs asynchronously
    Two controllers collided: the Rev1.1's blocking I2C and ADC work
    before each send moved it up to ~180 µs off its slot.
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2026-11-01 Calibration view: stored values beside it, axes drawn as reported
2026-11-04 PCB: DigiKey part numbers in schematics and BOMs
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2026-11-04 PCB release: name every file for its board and revision
2026-11-04 Dongle board: shorter title
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2026-11-04 Licenses: aux button guide is a CC BY-NC-SA remix
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2026-11-05 Configurator: Help → About with the license and notices
2026-11-08 Todo: USB IDs, settings file, debug UART, XInput battery
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2026-11-12 Docs: photos of the controller, dongle and assembled board
